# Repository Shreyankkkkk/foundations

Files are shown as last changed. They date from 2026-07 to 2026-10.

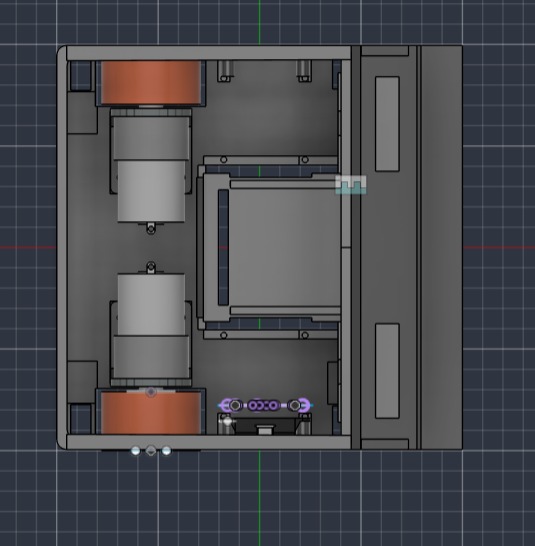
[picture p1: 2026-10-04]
projects/sumo-robot/design/cad-v2/WhatsApp Image 2026-09-25 at 10.48.36.jpeg

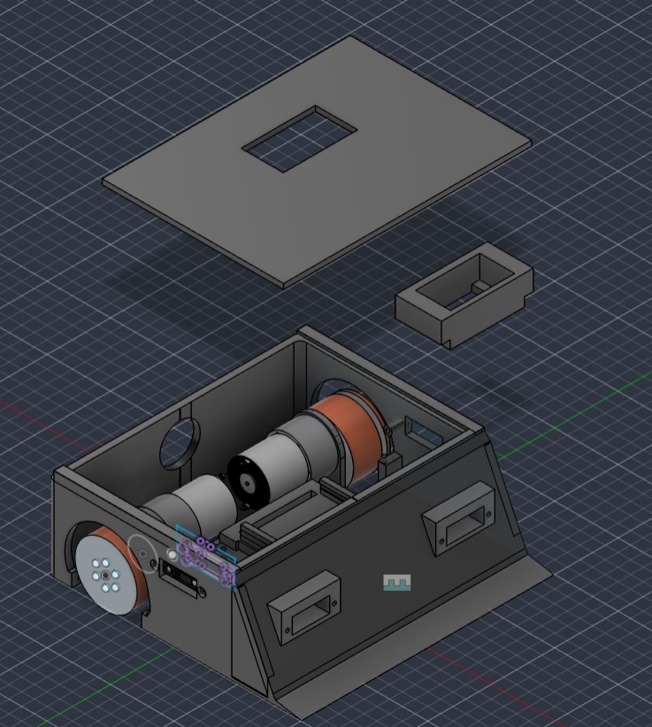
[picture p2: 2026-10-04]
projects/sumo-robot/design/cad-v2/WhatsApp Image 2026-09-25 at 10.48.32.jpeg

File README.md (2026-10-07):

# Foundations

A public log of everything I study, build and earn: notes, exercises, projects, certificates and plans, with dates.

**Shreyank**, second-year Mechatronics Engineering student at the University of Wollongong in Dubai. Long-term goal: quantitative finance, through both discretionary trading and systematic/quant development.
Contact: [LinkedIn](https://www.linkedin.com/in/shreyank-bhatt-63624a382/) · bhattshreyanks@gmail.com

## Where to look

| I want to see | Go to |
|---|---|
| What I did and when | [`journal/`](journal/): one dated ledger per month |
| What I built | [`projects/`](projects/): each project has a `STATE.md` (where it stands) and a `LOG.md` (what changed, when, why) |
| What I studied | [`learning/`](learning/): programming, mathematics, AI, engineering, finance |
| What I earned | [`certificates/`](certificates/): indexed by domain |
| What I plan next | [`roadmap/`](roadmap/) |

## Projects

| Project | Status | Summary |
|---|---|---|
| [`sumo-robot`](projects/sumo-robot/) | Finished (Oct 2026) | Autonomous sumo robot for the Dubai TechBots League SumoX-26; firmware v1.0 to v2.4, sensor calibration, CAD. Retrospective in the folder. |
| [`monte-carlo-simulation`](projects/monte-carlo-simulation/) | Active | Monte Carlo trading simulation in Python (Numba, joblib); modular rewrite in `current/`, earlier versions in `archive/`. |
| [`quant-finance-sim-forage`](projects/quant-finance-sim-forage/) | To redo | Forage quant-finance simulation; early attempt only. |

## Learning

Python (notes + exercises), Git & GitHub, data analysis with pandas (started), embedded C on Arduino (started), statistics (notes), Claude and LLM basics (notes). Details and status: [`learning/README.md`](learning/README.md).

## How this repo is kept

- Structure and rules for AI assistants are in [`AI-CONTEXT.md`](AI-CONTEXT.md). Logging is done with an AI assistant connected to this folder; AI-assisted work is recorded as such in each project's `LOG.md`.
- All names are lowercase kebab-case. Books, vendor files and coursework are kept local and not published.

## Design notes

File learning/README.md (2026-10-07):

# Learning

Notes and exercises, grouped by subject. Layout inside a topic: `notes/`, `exercises/`, `datasets/`, `projects/` (only where there is content). Plans live in `roadmap/`; dates live in `journal/`.

| Area | Folder | Status |
|---|---|---|
| Python | `programming/python` | notes (algorithms, OOP, data structures, debugging) + 17 exercises |
| Git & GitHub | `programming/git-github` | notes + cheat sheet |
| Data analysis | `programming/data-analysis` | started: pandas note + one exercise |
| Embedded C / Arduino | `programming/embedded-arduino` | fundamentals note + exercises 01-04 |
| APIs & automation | `programming/apis-automation` | planned |
| Statistics | `mathematics/statistics-essential` | notes 1-7 + cheat sheet |
| Quant maths plan | `mathematics/quant-math-curriculum.md` | reading plan |
| Claude / LLMs | `ai/notes` | Claude 101, Claude Code, how LLMs work |
| CAD | `engineering/fusion360-cad` | planned |
| Finance | `finance/` | planned |

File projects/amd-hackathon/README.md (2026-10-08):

# AMD Hackathon (Lablab x AMD AI Academy Challenge)

Individual, three-month AMD developer program (2026-09-01 to 2026-12-01): AI Academy courses, bi-weekly mini-challenges (OCR, RAG, agents, fine-tuning), XP leaderboard, cash prizes for the first three builders to reach Legend rank.

- Current status and rules: `STATE.md`
- Dated changes: `LOG.md`
- Digest of the brief: `docs/brief.md`

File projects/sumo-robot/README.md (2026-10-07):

# Sumo-Robot (SumoX-26)

Autonomous sumo robot (Arduino UNO Q, 20x20 cm, 3 kg) built for the Dubai TechBots League SumoX-26. Competed 2026-10-04 and was eliminated after three matches.

Start with `STATE.md` (result, constants with calculations, hardware, rules), then `Retrospective.md` (what worked and what didn't, by stage). `LOG.md` is the history.

| Folder | Holds |
|---|---|
| `docs/specs/` | wiring, strategy and reference documents |
| `docs/rulebook/` | competition rulebook and briefing slides |
| `design/` | `cad-v1` and `cad-v2` models, `parametric` wedge and deck scripts |
| `firmware/strategy/` | firmware versions `v1.0` to `v2.4` (v2.4 was on the board), `CodeGuide.md` |
| `firmware/tests/` | sensor, motor and calibration sketches |
| `notes/` | notes, dated scans (`scans/`), and per-chat summaries (`chat-summaries/`) |

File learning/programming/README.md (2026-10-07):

# Programming

| Folder | Contents |
|---|---|
| `python/` | `notes/` (concept notes with runnable demos), `exercises/` (solved problems), `data-structure-algorithm/` |
| `git-github/` | `notes/` (fundamentals, cheat sheet) |
| `data-analysis/` | `notes/`, `exercises/`, `datasets/` |
| `embedded-arduino/` | `notes/arduino-fundamentals.md`, `exercises/01-04` (blink, button, multi-sensor priority, toggle edge detection) |
| `apis-automation/` | planned |

Index of all learning areas: `../README.md`.

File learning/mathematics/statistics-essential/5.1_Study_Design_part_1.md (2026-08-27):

# Source and attribution

These are my personal study notes based on the Khan Academy Statistics course.

- Course: Statistics
- Provider: Khan Academy
- Source: https://www.khanacademy.org/math/probability
- Copyright: © 2025 Khan Academy. All rights reserved.

## These notes are independently written summaries for educational and reference purposes and are not official Khan Academy course materials.

# Intoduction to Plannning a Study

## Lesson 1 : Identifying a Sample and Population

### Population

A **population** is the **entire group of individuals** that a study is interested in.

$$\boxed{\text{Population}=\text{entire group being studied}}$$

The population is the group that researchers ultimately want to learn about.

---

### Sample

A **sample** is a **subset of the population** that is actually observed, surveyed, or measured.

$$\boxed{\text{Sample}=\text{part of the population actually studied}}$$

The sample is used to gather information about the larger population.

---

### Example: Riverview High School

Administrators at Riverview High School want to know how seniors feel about the lunch offerings in the school's cafeteria.

They randomly survey **100 seniors**.

Therefore:

$$\boxed{\text{Population}=\text{all seniors at Riverview High School}}$$

and:

$$\boxed{\text{Sample}=\text{the 100 seniors who were surveyed}}$$

The 100 seniors are only a subset of all the seniors at the school.

$$
\boxed{\text{Sample}\subseteq\text{Population}}$$

---

### Population vs Sample

| Term | Meaning | Riverview Example |
| --- | --- | --- |
| **Population** | Entire group of interest | All seniors at Riverview High |
| **Sample** | Subset actually studied  | 100 seniors surveyed |

A useful way to remember the difference:

$$
\boxed{\text{Population}=\text{WHO we want information about}}$$

$$
\boxed{\text{Sample}=\text{WHO we actually collect information from}}$$

---

### Why Use a Sample?

Researchers often cannot or do not want to collect data from every member of the population.

Studying the entire population may be:

- impractical
- expensive
- time-consuming
- difficult to organize

Instead, researchers can select a sample and use its results to learn about the population.

The basic process is:

$$
\boxed{\text{Population}\rightarrow\text{Sample}\rightarrow\text{Collect data}\rightarrow\text{Learn about population}}$$

---

### Random Sample

A **random sample** is a sample selected randomly from the population.

In the Riverview example, the administrators randomly select 100 seniors.

$$
\boxed{\text{Random sample}=\text{sample selected randomly from the population}}$$

Random sampling helps reduce the risk that the sample is systematically different from the population.

---

### Identifying the Population

When identifying the population, ask:

> **Who are the researchers trying to learn about?**

For the Riverview example, the researchers want to know how **all seniors at Riverview High** feel about the cafeteria.

Therefore:

$$\boxed{\text{Population}=\text{all seniors at Riverview High}}$$

It is **not**:

- all high school seniors in the world
- all students at Riverview High
- all teenagers

The population must match the group the study is actually trying to understand.

---

### Identifying the Sample

When identifying the sample, ask:

> **Who was actually surveyed, observed, or measured?**

In the Riverview example, the administrators surveyed 100 seniors.

Therefore:

$$\boxed{\text{Sample}=\text{the 100 seniors surveyed}}$$

It is not all seniors at the school because only 100 of them were actually surveyed.

---

### Common Mistakes

#### Mistake 1: Making the population too large

Suppose the study is about seniors at one particular school.

Incorrect:

$$\boxed{\text{Population}=\text{all high school seniors in the world}}$$

Correct:

$$\boxed{\text{Population}=\text{all seniors at the school}}$$

The population depends on the **specific group the researchers want to learn about**.

---

#### Mistake 2: Calling the entire population the sample

If 100 seniors were surveyed, the sample is not all seniors.

Incorrect:

$$\boxed{\text{Sample}=\text{all seniors at Riverview}}$$

Correct:

$$\boxed{\text{Sample}=\text{100 seniors who were surveyed}}$$

---

### Example

A university wants to know how students feel about its online classes.

The university randomly surveys 500 students.

Then:

$$\boxed{\text{Population}=\text{all students at the university}}$$

$$\boxed{\text{Sample}=\text{the 500 students surveyed}}$$

The 500 students provide information that can be used to learn about the larger population.

---

### Quick Exam Strategy

When a question asks you to identify the population and sample:

**Step 1:** Ask who the researchers want to learn about.

$$\boxed{\text{Population}}$$

**Step 2:** Ask who was actually surveyed, observed, or measured.

$$\boxed{\text{Sample}}$$

Remember:

$$\boxed{\text{Population}\rightarrow\text{larger group}}$$

$$\boxed{\text{Sample}\rightarrow\text{smaller group actually studied}}$$

---

### Key Takeaways

> **Population = the entire group we want to learn about.**

$$\boxed{\text{Population}=\text{entire group of interest}}$$

> **Sample = the part of the population that we actually study.**

$$\boxed{\text{Sample}=\text{subset actually studied}}$$

The most important relationship is:

$$
\boxed{
\text{Sample}\subseteq\text{Population}
}
$$

For the Riverview example:

$$\boxed{\text{Population}=\text{all seniors at Riverview High}}$$

$$\boxed{\text{Sample}=\text{100 seniors surveyed}}$$

### Memory Trick

> **Population = WHO you WANT to know about.**
>
> **Sample = WHO you ACTUALLY ask or measure.**

The overall idea:

$$
\boxed{
\text{Sample}
\rightarrow
\text{Use data to learn about}
\rightarrow
\text{Population}
}
$$

---

### Video

[Identifying a sample and population](https://www.youtube.com/watch?v=VPM84_yfx5Q)

---

## Lesson 2 : Generalizing Results to a Population

### What Does It Mean to Generalize?

**Generalizing** means using the results from a sample to make conclusions about a **larger population**.

For example, researchers may survey a sample of students and use their responses to learn about a larger group of students.

The basic idea is:

$$
\boxed{
\text{Sample results}
\rightarrow
\text{Conclusions about a population}
}
$$

However, we can only safely generalize to a population that the sample **properly represents**.

---

### Example: University Residence Halls

A large university has **24 residence halls**.

Estella oversees **12 of those residence halls**.

Her department takes a **large simple random sample** of first-year students who live in those 12 residence halls.

The students are surveyed about their overall satisfaction with campus living.

The important details are:

- The sample contains **first-year students**.
- They live in **Estella's 12 residence halls**.
- The sample was **large**.
- The sample was selected using a **simple random sample**.

Therefore, the survey results can safely be generalized to:

$$
\boxed{
\text{All first-year students who live in those 12 residence halls}
}
$$

---

### Why Can't We Generalize to All First-Year Students?

The sample only includes first-year students who live in the **12 residence halls managed by Estella**.

There may be other first-year students living in the university's other 12 residence halls.

Those students were not part of the population from which the sample was selected.

Therefore:

$$
\boxed{
\text{Cannot generalize to all first-year students at the university}
}
$$

The sample may not represent students living in the other residence halls.

For example, Estella's 12 residence halls could be:

- the closest to campus
- the furthest from campus
- unusually good
- unusually poor
- different in some other way

Because the sample only comes from those 12 halls, we cannot assume that the results apply to students living elsewhere.

---

### Why Does Simple Random Sampling Matter?

A **simple random sample** gives members of the population a fair chance of being selected.

If the sample is a large simple random sample from a particular population, the results can generally be generalized to that population.

The key relationship is:

$$
\boxed{
\text{Random sample}
\rightarrow
\text{Can generalize to the population sampled from}
}
$$

But remember:

> **Random sampling does not automatically allow you to generalize to everyone.**

You can only generalize to the population from which the random sample was actually selected.

---

### The Sampling Population

The **sampling population** is the group from which the sample was actually selected.

In this example:

$$\boxed{\text{Sampling population}=\text{first-year students living in the 12 residence halls}}$$

The sample is randomly selected from this group.

Therefore, this is the population to which the results can be generalized.

---

### Important Distinction

There are three groups to keep track of:

1. **The entire university**
2. **The 12 residence halls managed by Estella**
3. **The students actually surveyed**

The survey only samples from group 2.

Therefore:

$$\boxed{\text{Population}=\text{first-year students living in the 12 residence halls}}$$

and:

$$\boxed{\text{Sample}=\text{large random sample of those students}}$$

---

### What About Students Beyond Their First Year?

The survey only sampled **first-year students**.

Second-year, third-year, and fourth-year students were not included.

Therefore, the results cannot safely be generalized to:

$$
\boxed{
\text{All students living in the 12 residence halls}
}
$$

Why?

Because students beyond their first year may have different experiences and opinions about campus living.

The sample was specifically drawn from **first-year students**.

---

### Generalization Rule

When deciding whether survey results can be generalized, ask:

> **Who could have been selected for the sample?**

The answer identifies the population to which the results can be generalized.

For example:

$$
\boxed{
\text{Sample selected from population}
\rightarrow
\text{Results can be generalized to that population}
}
$$

But:

$$
\boxed{
\text{Sample selected from population A}
\not\rightarrow
\text{Automatically generalizable to population B}
}
$$

---

### Example

Suppose a school has 1,000 students.

Researchers randomly survey 100 students from the entire school.

Then the results can potentially be generalized to:

$$
\boxed{
\text{All 1,000 students at the school}
}
$$

But suppose instead they randomly survey 100 students from only the school's basketball team.

Then the results can only be generalized to the population represented by that sampling process, such as:

$$
\boxed{
\text{Students on the basketball team}
}
$$

You cannot use the basketball team's opinions to automatically represent the entire school.

---

### Large Sample vs Population Coverage

A **large sample** is useful, but size alone does not determine what population you can generalize to.

For example, suppose you survey 5,000 students from only one residence hall.

Even though:

$$
\boxed{\text{Sample size}=5000}
$$

you still cannot automatically generalize the results to students living in every residence hall.

The sample must represent the population you want to make conclusions about.

Therefore:

$$
\boxed{
\text{Large sample}
\neq
\text{automatically representative of everyone}
}
$$

The **sampling method and sampling population** matter.

---

### Key Question for Exams

When asked:

> **"To which population can these results be generalized?"**

Ask:

### Step 1: Who was actually sampled?

Identify the group from which the researchers selected participants.

### Step 2: Was the sample randomly selected?

If it was a random sample, the results can generally be generalized to the population from which that sample was drawn.

### Step 3: Check for restrictions

Look for restrictions such as:

- only first-year students
- only students in certain residence halls
- only members of a particular group
- only people from a particular location

The generalization must respect these restrictions.

---

### Riverview Connection

This connects directly to Lesson 1.

In Lesson 1:

$$\boxed{\text{Population}=\text{all seniors at Riverview High}}$$

$$\boxed{\text{Sample}=\text{100 seniors surveyed}}$$

Because the 100 seniors were randomly sampled from the seniors at the school, the survey results can potentially be generalized to:

$$
\boxed{
\text{all seniors at Riverview High}
}
$$

The same principle applies here.

---

### Important Exam Rule

$$
\boxed{
\text{Random sample}
\rightarrow
\text{generalize to the population sampled from}
}
$$

But:

$$
\boxed{
\text{Do not generalize beyond the population represented by the sample}
}
$$

For the university example:

$$
\boxed{
\text{Generalize to:}
\text{first-year students in the 12 residence halls}
}
$$

Not:

$$
\boxed{
\text{All students at the university}
}
$$

and not:

$$
\boxed{
\text{All first-year students at the university}
}
$$

---

### Key Takeaways

> **A survey's results can only be generalized to the population from which the sample was appropriately selected.**

$$
\boxed{
\text{Sample}
\rightarrow
\text{Sampling population}
\rightarrow
\text{Generalization}
}
$$

A **large simple random sample** allows us to make conclusions about the population from which the sample was drawn.

$$
\boxed{
\text{Large simple random sample}
\rightarrow
\text{Generalizable to its sampling population}
}
$$

But remember:

$$
\boxed{
\text{Random sampling does not mean you can generalize to everyone}
}
$$

You must respect the characteristics of the sampled population.

### Memory Trick

> **Ask: "Who could have been picked?"**

That group is the population you can generalize to.

For the university example:

$$\boxed{\text{Who could have been picked?}=\text{first-year students living in the 12 residence halls}}$$

Therefore:

$$
\boxed{
\text{Generalize to that group}
}
$$

---

### Video

[Generalizing survey results to a population](https://www.youtube.com/watch?v=2FXwGI_debU)

---

## Lesson 3 : Types of Statistical Studies

### Experiment vs Observational Study

The two main types of statistical studies are:

### Experiment

An **experiment** actively assigns subjects to different groups and applies a treatment or condition.

Typically:

- Subjects are assigned to a **treatment group** or **control group**.
- The treatment group receives the treatment.
- The control group may receive a placebo or no treatment.
- The results are compared between the groups.

$$
\boxed{\text{Experiment}\rightarrow\text{actively assign treatments and observe results}}
$$

### Observational Study

An **observational study** does **not** assign treatments or actively put subjects into groups.

Instead, researchers collect and analyze data about what already exists.

$$
\boxed{\text{Observational study}\rightarrow\text{observe and collect data without assigning treatment}}
$$

---

### Types of Observational Studies

There are three important types:

| Type | What it does | Time direction |
| --- | --- | --- |
| **Retrospective** | Uses past data | Looks backward |
| **Prospective** | Collects data going forward | Looks forward  |
| **Sample survey** | Collects information from a sample now | Present |

---

#### Retrospective Study

A **retrospective study** looks at data from the **past**.

Researchers use existing records or previously collected information.

Memory trick:

> **Retro = backward**

$$
\boxed{\text{Retrospective}\rightarrow\text{past data}}
$$

**Example:** Analyzing students' Khan Academy usage from previous years.

---

#### Prospective Study

A **prospective study** follows a sample **into the future** and collects data over time.

Researchers select the sample first, then track the subjects.

Memory trick:

> **Prospective = forward**

$$
\boxed{\text{Prospective}\rightarrow\text{future data}}
$$

**Example:** Select 100 people and track their daily habits for the next year.

---

#### Sample Survey

A **sample survey** collects information from a sample **at the present time**, usually by asking questions or recording current information.

$$
\boxed{\text{Sample survey}\rightarrow\text{collect information now}}
$$

**Example:** Randomly selecting students and asking them how satisfied they currently are with their school.

---

### Quick Decision Guide

Ask these questions:

**1. Are researchers actively assigning a treatment?**

$$
\boxed{\text{Yes}\rightarrow\text{Experiment}}
$$

**2. No treatment is assigned. Are they using past data?**

$$
\boxed{\text{Yes}\rightarrow\text{Retrospective}}
$$

**3. No treatment is assigned. Are they tracking a sample into the future?**

$$
\boxed{\text{Yes}\rightarrow\text{Prospective}}
$$

**4. No treatment is assigned. Are they collecting information from people now?**

$$
\boxed{\text{Yes}\rightarrow\text{Sample survey}}
$$

---

#### Key Takeaway

$$\boxed{\text{Experiment}=\text{assign treatment}}$$

$$\boxed{\text{Retrospective}=\text{look backward}}$$

$$\boxed{\text{Prospective}=\text{look forward}}$$

$$\boxed{\text{Sample survey}=\text{ask/observe now}}$$

#### Memory Trick

> **Experiment = DO something**  
> **Retrospective = PAST**  
> **Prospective = FUTURE**  
> **Sample survey = NOW**

### Video

[Types of Studies](https://www.youtube.com/watch?v=zmXBbHDUgY4)

---

## Lesson 4 : Identifying Observational Studies

### Observational Study

An **observational study** collects data by observing existing conditions without assigning treatments.

The goal is often to identify a **relationship or correlation between variables**.

$$\boxed{\text{Observational study}=\text{observe variables without assigning treatment}}$$

---

### Example: Naming Cows

Researchers surveyed farmers in Great Britain about:

- whether their cows were given names
- the cows' milk yield

They found that farms where cows were named had an average milk yield **258 liters higher** than farms where cows were not named.

This is an **observational study** because the researchers did not tell farmers whether to name their cows. They simply observed what was already happening.

---

### Why It Is Not an Experiment

In an experiment, researchers would actively assign farmers to groups.

For example:

- Group 1 → name their cows
- Group 2 → do not name their cows

Then researchers would compare milk yields.

That did **not** happen in this study.

$$
\boxed{
\text{No treatment assignment}
\rightarrow
\text{Not an experiment}
}
$$

---

### Correlation vs Causation

The study found a **positive correlation** between naming cows and milk yield.

$$
\boxed{
\text{Naming cows}
\leftrightarrow
\text{Higher milk yield}
}
$$

However, this does **not** prove that naming cows causes higher milk production.

The correct conclusion is only that the variables are **associated/correlated** in the observed population.

$$
\boxed{
\text{Correlation}
\neq
\text{Causation}
}
$$

---

### Confounding Variable

A **confounding variable** is another variable that may be related to both variables being studied and could explain their association.

For example, a farmer's treatment of cows could affect both:

- whether cows are named
- milk production

Therefore, the observed relationship between naming cows and milk yield might be partly or entirely explained by another variable.

$$
\boxed{
\text{Confounding variable}
\rightarrow
\text{may influence both variables}
}
$$

---

### What Can Be Concluded?

Because this is an observational study, researchers can conclude that:

$$
\boxed{
\text{There is a positive correlation between naming cows and milk yield among the farmers studied}
}
$$

They **cannot** conclude:

$$
\boxed{
\text{Naming cows causes higher milk yield}
}
$$

---

### Quick Decision Guide

When identifying a study, ask:

**1. Did researchers actively assign a treatment?**

$$
\boxed{\text{Yes}\rightarrow\text{Experiment}}
$$

**2. Did they simply observe existing conditions and look for relationships?**

$$
\boxed{\text{Yes}\rightarrow\text{Observational study}}
$$

Then ask:

> **Can the study prove causation?**

For an observational study:

$$
\boxed{
\text{Usually no causal conclusion}
}
$$

Instead:

$$
\boxed{
\text{Observational study}
\rightarrow
\text{association/correlation}
}
$$

---

### Key Takeaways

> **Observational study = observe without assigning treatment.**

$$
\boxed{
\text{Observational}
\rightarrow
\text{correlation/association}
}
$$

> **Correlation does not prove causation.**

$$
\boxed{
\text{Correlation}
\neq
\text{Causation}
}
$$

> **Confounding variables can help explain an observed association.**

### Memory Trick

> **Experiment = DO something.**  
> **Observational = WATCH what happens.**  
> **Correlation = relationship, not proof of cause.**

---

### Video

[Identifying observational studies](https://www.youtube.com/watch?v=tHFyaoIrV14)

---

## Lesson 5 : Understanding Causality

### Association vs Causality

An **association** means two variables are related.

**Causality** means a change in one variable actually **causes** a change in another.

$$
\boxed{
\text{Association}
\neq
\text{Causation}
}
$$

An observational study can show an association, but by itself it generally cannot prove that one variable causes another.

---

### Example: Smartphone Usage and Happiness

A study used approximately **5,000 randomly selected teenagers** and found that teenagers who spent more time on smartphones were, on average, less happy.

This shows an **association** between:

- smartphone usage
- happiness

$$
\boxed{
\text{More smartphone use}
\leftrightarrow
\text{Lower happiness}
}
$$

However, it does **not** prove:

$$
\boxed{
\text{More smartphone use}
\rightarrow
\text{Lower happiness}
}
$$

Jerry's conclusion that smartphone usage **causes** teenagers to be less happy is therefore not valid.

---

### Why Can't We Prove Causation?

There are several possible explanations for the association.

#### 1. Reverse Causation

The direction of causality could be reversed.

For example:

$$
\boxed{
\text{Lower happiness}
\rightarrow
\text{More smartphone use}
}
$$

Less happy teenagers might use their smartphones more.

---

#### 2. Confounding Variable

A third variable could affect both variables.

$$
\boxed{
\text{Confounding variable}
\rightarrow
\begin{cases}
\text{smartphone usage}\\
\text{happiness}
\end{cases}
}
$$

For example, another factor could make a teenager both less happy and more likely to use a smartphone.

---

### When Can We Make a Causal Conclusion?

A well-designed **experiment** can provide evidence for causality.

Researchers can:

1. Randomly assign subjects to groups.
2. Give the treatment group a treatment.
3. Give the control group no treatment or a placebo.
4. Compare the outcomes.

For example:

$$
\boxed{
\text{Random assignment}
\rightarrow
\text{Treatment vs Control}
\rightarrow
\text{Compare outcomes}
}
$$

Because the researchers actively assign the treatment, an experiment can establish evidence of a **cause-and-effect relationship**.

---

### Observational Study vs Experiment

| Study type | What researchers do | Causal conclusion? |
|---|---|---|
| **Observational study** | Observe existing conditions | Generally **no** |
| **Experiment** | Assign treatments to groups | **Can** support causality |

The key difference is:

$$\boxed{\text{Experiment}=\text{researchers assign treatment}}$$

$$\boxed{\text{Observational study}=\text{researchers observe without assigning treatment}}$$

---

### Important Exam Rule

If a question describes a study where researchers **only observe** people's existing behavior:

$$
\boxed{
\text{Association/correlation}
\text{ can be concluded}
}
$$

but:

$$
\boxed{
\text{Causation}
\text{ cannot generally be concluded}
}
$$

If researchers **randomly assign a treatment**:

$$
\boxed{
\text{Experiment}
\rightarrow
\text{causal conclusions may be possible}
}
$$

---

### Key Takeaways

> **Observational study → association, not causation.**

> **Experiment with appropriate random assignment → can provide evidence of causation.**

$$
\boxed{
\text{Observe}
\rightarrow
\text{Association}
}
$$

$$
\boxed{
\text{Randomly assign treatment}
\rightarrow
\text{Causality can be investigated}
}
$$

### Memory Trick

> **Observe = Association**  
> **Assign = Causation**

---

### Video

[Understanding when a conclusion about causality can be made from a study](https://www.youtube.com/watch?v=xSvvjdZjgl8)

---

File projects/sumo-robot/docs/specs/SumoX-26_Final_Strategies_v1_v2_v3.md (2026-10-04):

# SumoX-26 Final Strategy & Behavior Specification

This document serves as the definitive guide to the behavior and logic implemented in the SumoX-26 robot. It describes the shared core, the specific combat strategies, and the tactical optimizations that govern the robot's actions.

## 1. System Architecture & Priority
The robot operates as a high-priority state machine. In every loop, the following priority is enforced:
1. **Emergency Stop**: If the `START_BUTTON` (A4) is released, motors stop immediately and the robot returns to a waiting state.
2. **Edge Recovery**: If any edge sensor detects white, all other logic is bypassed to execute `edgeRecover()`. This event also resets target tracking state to prevent "ghost" attacks after recovery.
3. **Target Tracking**: If an opponent is detected, the robot enters the `approachTarget()` and `attack()` sequence.
4. **Search Arc**: If no opponent is detected and the robot is not in a blind-window attack, it executes a circular search sweep.

---

## 2. The Shared Core (Common Logic)

### A. Startup & The Randomized Start
To avoid predictability and "wedge-locks" at the start of a match, the robot uses a **Randomized Start Palette**.
- **The Sequence**: After the mandatory 5-second countdown, the robot randomly selects one of four maneuvers:
    - **Balanced Offset**: 200ms pivot $\rightarrow$ 300ms forward.
    - **The Aggressor**: 100ms pivot $\rightarrow$ 400ms forward (fastest approach).
    - **The Flanker**: 300ms pivot $\rightarrow$ 200ms forward (wide angle).
    - **The Blitz**: 0ms pivot $\rightarrow$ 300ms straight burst (maximum aggression).
- **Randomness**: The system is re-seeded using `micros()` at the moment the round-start button is confirmed, ensuring unique patterns even across power-cycles.
- **Safety**: All start maneuvers are safety-aware; if an edge is hit during the start move, it immediately triggers `edgeRecover()`.

### B. Sensor Processing
- **Opponent Sensing**: GP2Y0A21 sensors are sampled every 40ms. A rolling median buffer of 5 samples is used to eliminate noise before comparing against `DIST_THRESHOLD` (400).
- **Sample Gating**: Tracking logic is gated by the sample count; state changes (like counting lost targets) only occur when a new physical sample is read, preventing CPU-speed logic errors.
- **Edge Sensing**: TCRT5000 sensors are polled digitally. Any "White" detection (`HIGH`) triggers an immediate interrupt.

### C. Edge Recovery & Repositioning
- **`edgeRecover()`**: A state machine that determines the direction of the edge hit (front, back, or corner) and executes a deterministic retreat and pivot. It includes ambiguity handling (e.g., safe-pivot fallbacks) when multiple sensors trigger.
- **`reposition()`**: A fallback maneuver used when a target is lost. It nudges the robot forward or backward for 300ms to change its vantage point.
- **`executeBalancedOffset()`**: A specific version of repositioning used after losing a target, shifting the robot slightly to avoid a head-on collision on the next attempt.

---

## 3. Combat Strategies

### Strategy 1: Flanking (Proportional Tracking)
Designed for smooth, curving approaches.
- **Approach**: Uses a P-controller based on the difference between left and right sensor readings.
- **Hard Override**: If a side sensor is triggered, the robot bypasses proportional math and executes a maximum-rate turn to snap back onto the target.
- **Steering**: Otherwise, it calculates a `correction` value ($\text{Kp} = 0.5$). The robot doesn't pivot; it drives in a continuous arc toward the opponent.
- **Engagement**: Once the opponent is squared up (error $< 20$), it commits to the attack.

### Strategy 2: Baseline (Discrete Tracking)
Designed for reliability and sharp corrections.
- **Approach**: Uses discrete steering states (`STEER_LEFT`, `STEER_RIGHT`, `STEER_STRAIGHT`).
- **Hysteresis**: To prevent "jitter" between left and right turns, the robot uses a `SIDE_TURN_MARGIN` (25) and a `SIDE_TURN_HYSTERESIS` (10) zone.
- **Confirmation**: A steering change is only committed if the target remains in that direction for 50ms.
- **Engagement**: Once front sensors are strongest, it commits to the attack.

---

## 4. Tactical Optimizations (The "Combat Edge")

### A. Active Push Correction
The robot does not simply drive straight when attacking. It applies a continuous steering correction during the push:
- **Logic**: `drive(ATTACK_SPEED + correction, ATTACK_SPEED - correction)`.
- **Purpose**: Keeps the robot's wedge centered on the opponent even if the opponent drifts or the robot slips.
- **Gain (Strategy 2)**: $\text{Push Kp} = 2$.

### B. The Hammer Attack & Blindness Protection
To win a "lock" where both robots are pushing against each other, the robot employs PWM oscillation:
- **Hammer Logic**: Rapidly toggles the base attack speed between `ATTACK_SPEED` (240) and `(ATTACK_SPEED - HAMMER_AMPLITUDE)` (190) every 100ms to break static friction.
- **Blindness Protection**: Once a push is committed (latched via `attackDeadline`), the robot continues to hammer for a short window (`ATTACK_COMMIT_MS`) even if sensor contact is lost. This ensures the robot doesn't abort an attack just because the opponent entered the sensor's near-field blind zone.

---

## 5. Calibration Cheat Sheet (Current Values)

| Parameter | Value | Unit/Description |
|---|---|---|
| **Sensing** | | |
| `DIST_THRESHOLD` | 400 | ADC value for detection |
| `SENSOR_SAMPLES` | 5 | Rolling buffer size |
| **Search** | | |
| `SEARCH_SLOW_SPEED` | 120 | PWM for slow motor |
| `SEARCH_FAST_SPEED` | 180 | PWM for fast motor |
| `SEARCH_FIRST_ARC_MS` | 600 | Initial pivot duration |
| `SEARCH_ARC_FLIP_MS` | 1100 | Standard arc flip duration |
| **Approach** | | |
| `APPROACH_SPEED` | 165 | Base approach speed |
| `TURN_SPEED` | 100 | Pivot speed during approach |
| `S1_Kp` | 0.5 | Proportional gain |
| `S1_DEADBAND` | 20 | Error threshold for attack |
| `S2_MARGIN` | 25 | Side detection threshold |
| **Attack** | | |
| `ATTACK_SPEED` | 240 | Base push power |
| `HAMMER_AMPLITUDE` | 50 | PWM oscillation depth |
| `HAMMER_PERIOD_MS` | 100 | Oscillation frequency |
| `S2_PUSH_KP` | 2 | Push correction gain |
| **Safety** | | |
| `REPOSITION_MS` | 300 | Nudge duration |
| `EDGE_RECOVER_SPEED` | 170 | Retreat speed |
| `OFFSET_SPEED` | 150 | Maneuver speed |

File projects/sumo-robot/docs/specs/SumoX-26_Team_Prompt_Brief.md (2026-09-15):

# SumoX-26 Team Brief — paste this into your own Claude chat

We're building an autonomous sumo robot for the **Dubai Techbots League SumoX-26** (Besomi Academy × Arduino × Qualcomm × Canadian University Dubai). Use the block below to get Claude up to speed instantly, then jump to your role's starter prompt.

---

## STEP 1 — Paste this shared context into a new Claude chat first

```
I'm on a team building an autonomous sumo robot for the Dubai Techbots League
SumoX-26 competition (organized by Besomi Academy, with Arduino and Qualcomm
as sponsors). Here are the key rules:

- Weight limit: 3 kg max
- Footprint: 20cm x 20cm max at start (no height limit, and the robot CAN
  change shape/size after movement begins, as long as all parts stay attached
  to the main body)
- Controller: MUST use the Arduino UNO Q as the primary/only microcontroller
  (no other microcontrollers allowed). It's a dual-brain board: an STM32
  microcontroller for real-time motor/sensor control, plus a Qualcomm
  QRB2210 Linux processor capable of running a camera and AI models.
- The robot must be 100% autonomous - remote control is strictly banned
- Arena: circular wood, 1.5m diameter, white 3cm frame, black surface, two
  brown 20cm center lines
- Round: max 3 minutes, robot must stay stationary for 5 seconds after
  activation before moving
- Match = best of 2 rounds (3rd if tied 1-1)
- Rule violations to avoid: front of the robot (blade/wedge) must NOT be
  white or any color that could interfere with sensor readings; no magnets,
  suction, vacuum wheels, or adhesives to grip the arena; no liquids, gases,
  powders, or projectiles; 3 warnings in one round = automatic round loss;
  6 total warnings = disqualification; any robot part detaching = 1 warning
  per part

My team already has a full build playbook covering: sumo robot world
championship research (All Japan Robot-Sumo Tournament history and past
winners), mechanical design (low center of gravity, wedge front, motor/gear
selection), electronics (motor driver, battery, opponent + edge sensors),
and a search -> attack -> edge-avoid programming logic. I'm now going deeper
on one specific part of the build. Please treat me as a beginner in this
specific area and build up my understanding step by step as we go, the same
way you'd teach someone new to the topic, then increase depth based on my
follow-up questions.
```

---

## STEP 2 — Add your role's starter prompt on top of that

Pick whichever matches what you're focusing on. If your team hasn't split roles yet, use the General one.

### 🔧 Mechanical / chassis lead
```
My focus is the mechanical build: chassis, wedge front, wheels, motor
mounting, and weight distribution. Help me design this step by step -
starting with material choice (aluminum vs polycarbonate vs HDPE), then
chassis shape and wedge geometry, then wheel/motor mounting, then a full
weight budget that lands at or just under 3kg with room for ballast.
Ask me what tools/materials I actually have access to before recommending
specifics.
```

### ⚡ Electronics / sensors lead
```
My focus is the electronics: the Arduino UNO Q setup, motor driver
selection, battery choice, and the opponent-detection + edge-detection
sensors. Walk me through setting up the UNO Q from scratch first (App Lab,
the MCU vs MPU split, running a first test sketch), then help me pick and
wire a motor driver and sensors that fit a 3kg autonomous sumo robot. Explain
each component's job before we pick parts.
```

### 💻 Programming / code lead
```
My focus is the code: the robot's decision logic (search -> attack ->
edge-avoid state machine) running on the Arduino UNO Q. Help me build this
from scratch, starting with the simplest possible version (basic edge
avoidance + move forward), then layer in opponent detection, then attack
behavior, then tuning. If it's useful, also explain how I could eventually
use the UNO Q's camera/AI side for smarter opponent detection as a stretch
goal - but let's get the reliable IR-sensor version working first.
```

### 🧭 General / not yet specialized
```
I don't have a specific role locked in yet. Can you help me understand the
full build process end to end at a beginner level - mechanical, electronics,
and code - so I can see which part I'm most drawn to, then we go deep on
that one?
```

---

## Notes for whoever's coordinating

- Everyone should also upload the actual **Dubai Techbots League SumoX-26 Rulebook PDF** to their own chat if they have it, so their Claude has the full original wording, not just this summary.
- Since each teammate's chat is separate, decisions made in one chat won't automatically show up in another — plan for someone (probably the Team Leader) to consolidate what each person's chat produces into one shared doc or group chat before final assembly.
- If two teammates' chats land on conflicting recommendations (e.g. different motor torque suggestions), that's normal — bring both back to the group and decide together rather than assuming either Claude session has the full picture.

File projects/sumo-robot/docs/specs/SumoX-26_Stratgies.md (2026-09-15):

# Sumo Robot Strategy Specs — SumoX-26 (3kg class)

Hardware reference (from wiring diagram):
- LEFT BTS7960: RPWM → D5, LPWM → D6, R_EN+L_EN → D7
- RIGHT BTS7960: RPWM → D9, LPWM → D10, R_EN+L_EN → D8
- GP2Y0A21 distance sensors ×4 (analog, opponent detection): A0, A1, A2, A3
  - Assign each to a mounting position before coding, e.g. FL (front-left), FC-L (front-center-left), FC-R (front-center-right), FR (front-right)
- TCRT5000 edge sensors ×4 (digital, HIGH on black / LOW on white or vice versa — confirm with a multimeter test first): D3, D4, D12, D13
  - Assign each to a corner: e.g. front-left, front-right, back-left, back-right
- Start button: D2 + GND

Tunables to determine through bench testing (placeholders — do not guess final values, calibrate against your actual sensors and arena):
- `DIST_THRESHOLD` — raw ADC value at which a GP2Y0A21 reading counts as "opponent detected"
- `EDGE_THRESHOLD` — digital state that counts as "white detected" per TCRT5000
- `PREDICT_WINDOW_MS` — how long to keep turning after signal loss (Strategy 2 only)
- `SWEEP_ANGLE_MS` — motor-on time for one side of the fallback oscillation (Strategy 2 only)
- `SPIN_STEP_MS` — motor-on time per search increment (Strategy 3 only)

---

## SHARED CORE (build this first, all 3 strategies call into it)

1. **Setup**: initialize all pins (motor PWM/enable pins as OUTPUT, GP2Y0A21 pins as ANALOG INPUT, TCRT5000 pins as INPUT, start button as INPUT_PULLUP). Do not enable motors yet.
2. **Wait for start signal**: poll the start button (or however the round is triggered). On trigger, begin the mandatory 5-second stationary window — sensors already reading, motors still at zero output.
3. **`readDistanceSensors()`**: read all 4 GP2Y0A21 analog pins each loop, return an array/struct of 4 values. Push each into a small rolling history buffer (last 3–5 samples per sensor) for use by Strategy 2.
4. **`checkEdges()`**: read all 4 TCRT5000 digital pins each loop. Return true immediately if any reads "white." This function must be called and checked *before* any drive command is issued, every loop, in every strategy — no exceptions.
5. **`edgeRecover(side)`**: reverse both motors briefly, then pivot away from the triggering side, then return control to the active strategy's search state.
6. **`attack()`**: drive both motors forward at full matched PWM. Call only once the target sensor is roughly front-facing. No steering corrections once called — commit fully.
7. **Main loop structure** (applies to all 3 strategies):
   ```
   loop():
     if checkEdges(): edgeRecover(triggeringSide); return
     readDistanceSensors()
     run the active strategy's state machine using the fresh sensor data
   ```

---

## STRATEGY 1 — Sit, Wait, Scan, Move-Toward-Angle, Attack

No prediction, no rotation search. Stay stationary until a detection occurs, square up, then commit.

1. **IDLE**: motors at zero, keep calling `readDistanceSensors()` and `checkEdges()` every loop.
2. **DETECT**: if any sensor's latest reading crosses `DIST_THRESHOLD`, move to TURN state. If multiple sensors cross it, pick the one with the strongest (closest) reading.
3. **TURN**: apply differential PWM (motor on the opposite side of the detected sensor runs, motor on the same side slows/stops) to rotate toward the detected sensor's direction. Keep reading sensors each loop.
4. **CHECK-SQUARED**: once the front-center sensor(s) become the strongest reading (i.e., you're roughly facing the target), exit TURN and call `attack()`.
5. **ATTACK**: call `attack()`. Stay in this state until either (a) `checkEdges()` fires (handled by shared core, interrupts everything), or (b) all sensors drop below threshold for several consecutive loops (target lost) — then return to IDLE.
6. **LOOP**: after an edge recovery or a lost target, return to IDLE and repeat from step 1.

---

## STRATEGY 2 — Sit, Wait, Scan, Predict, Turn, Attack

Same as Strategy 1, plus a predictive-continuation layer when the signal disappears mid-engagement, and a bounded fallback sweep instead of giving up.

1. **IDLE**: same as Strategy 1 step 1.
2. **DETECT**: same as Strategy 1 step 2. Also record the detected sensor's direction and the loop's timestamp as `lastKnownDirection` and `lastSeenTime`.
3. **TURN**: same as Strategy 1 step 3, continuously updating `lastKnownDirection` while a signal is present.
4. **CHECK-SQUARED → ATTACK**: same as Strategy 1 steps 4–5, also continuously updating `lastKnownDirection` while attacking (in case the opponent slides off to one side mid-charge).
5. **SIGNAL-LOST**: if all sensors drop below threshold while in TURN or ATTACK, do NOT return to IDLE immediately. Instead:
   - Enter PREDICT state: keep turning in `lastKnownDirection` for up to `PREDICT_WINDOW_MS`, re-checking sensors every loop in case the target reappears (if it does, jump straight back to TURN/ATTACK as appropriate).
6. **FALLBACK SWEEP**: if `PREDICT_WINDOW_MS` elapses with nothing detected, perform a bounded oscillation: turn one direction for `SWEEP_ANGLE_MS`, then the other direction for `SWEEP_ANGLE_MS`, checking sensors continuously. If detected during the sweep, jump to TURN.
7. **GIVE UP TO IDLE**: if the sweep also finds nothing after a set number of oscillations, return to IDLE and repeat from step 1.

---

## STRATEGY 3 — Rotate, Scan, Attack

Simplest and most robust. No stationary phase beyond the mandatory 5s, no prediction — continuous rotation until something is found.

1. **SEARCH**: starting the moment the 5s window ends, rotate continuously in one direction (one motor forward, one motor reverse, or one motor forward/one motor stopped — pick whichever turn radius suits your wedge geometry) at a moderate speed. Read all 4 sensors every loop.
2. **DETECT**: the instant any sensor crosses `DIST_THRESHOLD`, stop rotating.
3. **SQUARE-UP** *(optional, can be skipped for max simplicity)*: brief correction turn toward the strongest sensor before attacking, same logic as Strategy 1 step 3–4. If skipped, just attack immediately in whatever heading you stopped at.
4. **ATTACK**: call `attack()`. Stay until edge-override fires or the target is lost for several consecutive loops.
5. **LOOP**: on lost target or after edge recovery, return to SEARCH (step 1) and resume rotating.

---

## Suggested build/test order

1. Shared core (sensor reads, edge-override, attack) — test in isolation first.
2. Strategy 3 — fewest states, fastest to get working end-to-end. This is your safety-net baseline.
3. Strategy 1 — small delta from Strategy 3 (swap rotate-search for stay-still-and-turn-to-signal).
4. Strategy 2 — build last, since `PREDICT_WINDOW_MS` and `SWEEP_ANGLE_MS` need real bench tuning against your actual sensors and motor response time.

Wire a mode switch (digital input pin, or a `#define STRATEGY 1/2/3` flipped before each flash) so all three can be tested head-to-head in practice matches before deciding which one goes into the actual competition.

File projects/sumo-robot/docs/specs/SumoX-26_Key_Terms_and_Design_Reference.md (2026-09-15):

# SumoX-26 Build — Key Terms & Design Reference

A working glossary of everything you need to understand to design this robot correctly, tied to your actual components (JSumo Titan 12V/200RPM motors, 52×30mm wheels, Arduino Uno Q) and the Dubai Techbots League rulebook.

---

## 1. Motor & Drivetrain Terms

| Term | What it means | Why it matters for your build |
|---|---|---|
| **Stall torque** | The maximum rotational force a motor produces when its shaft is prevented from turning at all (0 RPM), usually given in kg·cm or N·m. | Your Titan motor's 10.35 kg·cm stall torque is the number that determines your maximum theoretical push force — this is what you're fighting the opponent with during contact. |
| **Stall current** | The current a motor draws when stalled — always much higher than running current, since there's no back-EMF to limit it. | Your motor draws 4.1A at stall. This is the number your motor driver and power system (fuses, wiring gauge, capacitors) must be rated to survive repeatedly, since ramming an opponent puts the motor near stall constantly. |
| **No-load current / no-load speed** | Current drawn and RPM reached when the motor spins freely with nothing attached. | Your motor's 60mA no-load current tells you baseline power draw when just driving around, not pushing. |
| **RPM (output)** | Rotational speed of the *output shaft*, after any internal gearbox — not the raw motor speed. | Your "200 RPM" spec is already the geared-down output speed, which is what determines your wheel speed. |
| **Gear ratio** | The reduction between the motor's internal shaft speed and the output shaft speed (e.g., 60:1 means the motor spins 60 times for every 1 output rotation). | Higher ratios trade speed for torque. Your Titan's built-in 60:1 gearbox is fixed — you're not choosing this yourself, but you should understand *why* it's high (sumo needs torque over speed). |
| **kg·cm (kilogram-centimeter)** | A torque unit — the force (in kgf) applied at a 1cm lever arm. Convert to linear push force at the wheel by dividing by wheel radius (in cm). | This is how you calculated push force per wheel earlier: 10.35 kg·cm ÷ 2.6cm radius (52mm wheel) ≈ 3.98 kgf per wheel. |
| **Watts (motor power rating)** | Electrical power the motor is designed to handle continuously (V × A). | Used to size your power system and confirm the motor won't overheat under sustained load. |

---

## 2. Traction & Mechanical Terms

| Term | What it means | Why it matters for your build |
|---|---|---|
| **Coefficient of friction (μ)** | A ratio describing how much grip exists between two surfaces (wheel and arena floor). Max friction force = μ × Normal force (weight on the wheel). | This is your *actual* limiting factor, not motor torque — if μ × weight is less than your motor's theoretical push force, your wheels slip instead of pushing. |
| **Contact patch** | The area of wheel actually touching the ground. | Wider wheels (your 52×30mm) have a larger contact patch, which increases usable grip before slipping — this is why we picked it over the narrower 43×11mm option. |
| **Wedge angle** | The angle of your robot's front plate relative to the ground. | 8–12° (your target) lets the wedge slide under an opponent's chassis to lift/destabilize them, while staying shallow enough not to dig into the arena floor. |
| **Ground clearance** | Gap between the wedge's leading edge and the arena floor. | Your 0.5–1mm target is tight enough to get under most opponents without scraping or catching on the floor surface. |
| **Center of gravity (CG)** | The point where a robot's weight is balanced. | A low, rear-biased CG improves push stability and resistance to being lifted or flipped by an opponent's wedge. |
| **Weight distribution** | How the robot's total mass is spread across its footprint, especially over the drive wheels. | More weight on the drive wheels increases normal force → increases available friction → increases usable push force (ties directly into the μ × N relationship above). |

---

## 3. Electrical & Power System Terms

| Term | What it means | Why it matters for your build |
|---|---|---|
| **H-bridge** | A switching circuit (the core of any motor driver) that lets a motor spin forward or backward by controlling current direction. | Every motor driver you're evaluating (BTS7960, Cytron, etc.) is built around this. |
| **Motor driver current rating (continuous vs. peak)** | Continuous = current a driver can sustain indefinitely without overheating; peak = brief current it can survive. | Your driver needs continuous rating comfortably above your motor's 4.1A stall current — this was the deciding factor when comparing driver options earlier. |
| **PWM (Pulse Width Modulation)** | A technique for controlling motor speed by rapidly switching power on/off, varying the % of time it's "on" (duty cycle). | This is how your Arduino Uno Q will vary drive speed for PID-based steering corrections rather than just full on/off. |
| **Brownout** | A voltage drop severe enough to reset or glitch a microcontroller, often caused by a sudden current spike elsewhere in the circuit. | Your spec flagged this directly — motor stall current spikes on impact can brown out the Uno Q mid-match if the power system isn't buffered. |
| **Bulk/decoupling capacitors** | Capacitors placed near a power input to absorb sudden current demand spikes, keeping voltage stable. | The fix for the brownout risk above — placed on your VIN line. |
| **Voltage regulator / BEC (Battery Eliminator Circuit)** | A circuit that converts battery voltage down to a stable voltage for your control electronics, separate from the main motor power line. | Keeps your Uno Q's logic supply clean and isolated from the noisy, current-hungry motor circuit. |

---

## 4. Control & Sensing Terms

| Term | What it means | Why it matters for your build |
|---|---|---|
| **PID controller** (Proportional-Integral-Derivative) | An algorithm that continuously calculates the error between a target and current value, then smoothly adjusts output — instead of a jerky on/off response. | Central to your strategy: used both for smooth opponent-tracking turns and for keeping two drive motors matched during a straight-line charge. |
| **Kp, Ki, Kd** | The three tuning constants of a PID loop — Proportional (reacts to current error), Integral (corrects accumulated past error), Derivative (dampens overshoot by reacting to rate of change). | These *cannot* be copied from another robot — you'll tune them empirically on your assembled robot, as your spec correctly noted. |
| **Debounce / debounce timing** | Filtering logic that ignores rapid, spurious sensor state changes and only reacts to a sustained signal. | Prevents your robot from twitching left-right when both opponent sensors briefly trigger at once near contact. |
| **ADC (Analog-to-Digital Conversion)** | The process of converting a sensor's continuous analog voltage (like an IR distance sensor's output) into a digital value the Uno Q can read. | Relevant because the Uno Q's architecture differs from a classic AVR Arduino — worth confirming its analog input specs directly, since it's a newer Linux-based board. |
| **IR reflectance (edge) sensor** | A sensor that shines infrared light down and measures reflection to distinguish the dark arena floor from "no floor" (i.e., the edge). | Your edge-detection system — must be tuned against the rulebook's white 3cm arena frame, since the sensor is reading contrast, not distance. |
| **IR proximity/distance sensor** | A sensor that detects how far away a reflective object (the opponent) is. | Your opponent-detection/tracking system feeding into the PID loop. |
| **False-trigger filtering** | Logic to reject sensor readings caused by glare, lighting, or unintended reflective surfaces rather than the real target. | Needed because the rulebook's arena has a **white painted frame** — a strong reflective surface your edge sensors must correctly interpret as "the boundary," not ignore or misread. |

---

## 5. Rulebook-Driven Design Constraints (things the terms above must work within)

| Constraint | Rule reference | Design implication |
|---|---|---|
| **Max weight: 3kg** | 4.1 | Every component choice (motors, wheels, battery, chassis material) must be weighed against this budget — this is why we favored lighter/cheaper options where torque/traction weren't compromised. |
| **Max footprint: 20×20cm** (no height limit) | 4.2 | Leaves you room to go tall if needed, but constrains wedge width and wheelbase. |
| **Controller must be Arduino Uno Q — no other primary microcontroller allowed** | 4.4 | **This overrides my earlier suggestion to use a Nano instead.** You must learn the Uno Q's specific I/O, PWM, and ADC behavior (it's a newer Linux-based SBC, not a classic AVR board) since your whole PID/sensor/motor-driver logic has to run on it specifically. |
| **Fully autonomous — no remote control** | 4.4 | Your decision loop (edge check → opponent check → PID drive) must run entirely onboard with no human input after activation. |
| **Front/wedge must not be white or a color that affects sensor readings** | 4.5 | Confirms your matte non-white wedge finish decision was correct — this is a hard rule, not just good practice. |
| **No magnets, suction, vacuum wheels, or adhesives** | 4.6 | Confirms your traction strategy must come entirely from wheel width/compound (like the 52×30mm silicone wheel), not from artificially anchoring to the floor. |
| **5-second mandatory stationary period after activation** | 6.2 | Your control loop must include a hard-coded 5-second delay before any movement — moving early is an explicit warning-triggering offense (7.3). |
| **3-minute round timer** | 6.7 | Your search-pattern/engagement logic needs to be effective within this window — long, cautious search patterns risk timing out without contact. |
| **Arena: 1.5m diameter, white 3cm frame, black surface** | 5.1 | Confirms your edge sensors are distinguishing black (safe) from the white frame boundary (edge) — directly relevant to the false-trigger filtering concept above. |

---

## 6. What to Actually Study (in priority order)

1. **DC motor fundamentals** — torque/speed/current relationships, stall vs. running behavior. Directly explains every number on your motor's datasheet.
2. **Basic mechanics (torque → force conversion, friction)** — lets you calculate push force and understand why wheel width matters more than raw torque once you're traction-limited.
3. **Arduino Uno Q specifics** — since it's a newer Linux-based board rather than a classic AVR Arduino, its GPIO/PWM/ADC handling may differ from typical tutorials. Worth reading its official documentation directly rather than assuming it behaves like an Uno R3.
4. **PID control basics** — enough to implement and then manually tune Kp/Ki/Kd on your actual robot.
5. **Power electronics basics** — capacitor sizing for brownout protection, how voltage regulators/BECs work.
6. **Sensor debouncing and filtering logic** — small but critical code patterns that prevent erratic behavior near contact.

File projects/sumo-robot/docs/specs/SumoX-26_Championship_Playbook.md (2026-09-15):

# SumoX-26 Championship Playbook
### A complete, beginner-to-advanced guide to building a winning autonomous sumo robot for the Dubai Techbots League (Besomi Academy × Arduino × Qualcomm × Canadian University Dubai)

> **How to use this guide:** It's written so you can start at zero knowledge in any subsystem (mechanics, electronics, or code) and build up. Each part starts with "what this even means" before getting technical. Read it top to bottom once, then use it as a checklist while you build. When you want to go deeper on any one section — motor math, sensor code, whatever — just ask, and we'll zoom in from there.

---

## PART 1 — The World of Robot Sumo (learn from the champions)

### 1.1 Where this sport comes from
Robot sumo isn't new — it's one of the oldest and most respected robotics sports in the world, and understanding its history tells you exactly what wins.

<cite index="5-1">Robot-Sumo began in Japan in 1989, when FUJISOFT Inc. organized an experimental robot-sumo tournament that became the All Japan Robot Sumo Tournament</cite>. Since 1998, <cite index="5-1">FUJISOFT has worked with more than 30 countries, and the sport has spread and become one of the most popular robotics competitions in the world.</cite> That tournament — the **All Japan Robot-Sumo Tournament (AJRST)** — is the closest thing this sport has to a World Championship, and it's held every December in Tokyo, gathering national champions from around the globe to fight for the international title.

The physical rules of that original Japanese competition are almost identical to yours: <cite index="6-1">a robot sumo win happens when the opponent robot touches the outside area of the ring, the robot must be designed only to push, and weapons or damaging devices are prohibited. Robot sumo must weigh 3 kg or less and measure 20 cm × 20 cm or less, with no height restriction.</cite> That means your event is running the exact same weight class as the world's top tournament — you're not in some watered-down junior version, you're building to the same spec real champions use.

### 1.2 Champions worth studying
- **Sakin (Turkey)** — <cite index="3-1">Sakin placed 2nd at the 2014 All Japan International Robot Sumo Tournament, a competition where the reigning three-year-unbeaten Japanese champion was defeated for the first time — then went on to win 1st place outright in 2015.</cite> Lesson: dethroning Japan is possible with disciplined engineering, not just budget.
- **Senju (Sumozade-Era Robotics, Turkey)** — recognized as the <cite index="7-1">first non-Japanese team to win the Mega Sumo Autonomous world title</cite>, a genuine underdog story.
- **ThundeRatz (Brazil)** — <cite index="7-1">dominated the RoboCore 3kg RC sumo class for years with their robot "Stonehenge," known for engineering discipline.</cite>
- **Georgia Tech RoboWrestling (USA)** — an active university team that <cite index="4-1">competes annually at the All Japan Robot-Sumo Tournament grand final, and is also building 3kg autonomous bots for regional qualifiers like RSM International in Brazil, which draws over 1,000 competitors.</cite>

### 1.3 Where the sport is growing right now
- **Japan** — still the historic center of gravity, but <cite index="7-1">in a notable 2025 shift, FUJISOFT pivoted focus toward the smaller 50g Mini Sumo class specifically to lower the barrier to entry and spark innovation in micro-robotics</cite> — a sign the sport is actively evolving.
- **Brazil** — <cite index="5-1">home to RoboCore, which ran the first official national robot-sumo tournament in Brazil in 2008, and became "the Brazilian National Robotics Championship" through the 2010s.</cite>
- **Turkey, Romania, China** — <cite index="7-1">Turkey and Romania both field strong competitive scenes, and China's RobotChallenge hosts large-scale championships as well.</cite>
- **UAE** — your event (Dubai Techbots League, backed by Besomi Academy, Arduino, and Qualcomm) is part of a fast-growing regional robotics scene alongside events like MBZIRC and the Emirates Robotics Competition — this is a young but serious ecosystem, and being early gives you a real shot at being a name people remember.

### 1.4 The one lesson every champion shares
Every write-up on elite sumo teams comes back to the same idea, and it's worth internalizing before you touch a screwdriver:

> **"Speed is life, but traction is god."** A fast, powerful robot that can't grip the floor is worthless. **Weight matters** — every one of your 3,000 grams should be doing a job. **Sensors are eyes** — a robot that can't see the opponent or the edge, no matter how strong, will lose or drive itself off the arena.

---

## PART 2 — Decoding Your Rulebook (in plain language)

Before building anything, let's translate the official terms into beginner language, because misunderstanding these costs teams matches.

| Rulebook term | What it actually means |
|---|---|
| **Round** | One single fight, up to 3 minutes. Whoever loses the pre-round coin-toss places their robot first. |
| **Match** | Best of 3 rounds (win 2 to take the match). If it's 1–1, a 3rd deciding round happens. |
| **Warning (yellow card)** | An official strike against your team for a rule slip-up. 6 warnings in the whole event = automatic disqualification. |
| **Violation (red card)** | An immediate, single disqualifying offense (e.g., intentionally damaging the opponent's robot). Forfeits all points and prize eligibility instantly. |

### 2.1 The numbers you must design around

| Spec | Limit | Why it matters |
|---|---|---|
| Weight | ≤ 3 kg | This is the classic "Mega Sumo" weight class used worldwide — every gram should add pushing power or control, not decoration. |
| Footprint | ≤ 20 cm × 20 cm | Measured at the **start** — no height limit at all, which is a real design opportunity (see §3.2). |
| Controller | **Arduino UNO Q — mandatory, no other primary microcontroller allowed** | This is unusual and a genuine advantage — more on this in Part 3. |
| Control mode | 100% autonomous — remote control is strictly banned | Your robot has to think for itself in real time. |
| Arena | 1.5 m diameter, circular, wooden, white 3 cm frame, black surface, two 20 cm brown centre lines | Know this surface — you'll calibrate your sensors against these exact colors. |
| Round timer | Max 3 minutes, starts after both robots have been stationary for 5 seconds post-whistle | Moving before the 5 seconds is literally a *listed cause for a warning*. |

### 2.2 The five rules that quietly decide matches (read these twice)
1. **Your front (blade/wedge) must NOT be white**, or any color that could interfere with sensor readings. This isn't cosmetic — the arena frame is white, so a white robot front risks confusing edge-detection logic (yours or the opponent's), and referees will flag it.
2. **No suction, vacuum wheels, magnets, or adhesives** to grip the arena — traction has to come from honest tire grip.
3. **No liquids, gases, powders, or projectiles** — pure pushing only.
4. **Size can change *after* the round starts**, as long as everything stays attached to the main body — this legally allows a "deployable" design (see §3.2).
5. **3 warnings in a single round = automatic loss of that round.** A detached part (even a small one) costs a warning *per part* unless it clearly didn't affect the match — so build things to stay attached.

---

## PART 3 — The Build: Step by Step

We'll go in the order you should actually build: **plan → mechanics → electronics → code → test.** Each step assumes you're new to that specific skill.

### STEP 1 — Design Planning & Weight Budget
**Beginner concept:** A "weight budget" just means deciding, on paper, how many of your 3,000 grams go to each part *before* you buy anything — so you don't build a great chassis and then discover there's no weight left for motors.

A reasonable starting budget for a 3 kg competitive bot:

| Component | Typical weight |
|---|---|
| Chassis + wedge front | 400–700 g |
| 2× drive motors + gearboxes | 300–600 g |
| Wheels + tires | 100–200 g |
| Arduino UNO Q + motor driver + wiring | 150–250 g |
| Battery (LiPo) | 150–300 g |
| Sensors (opponent + edge) | 50–100 g |
| Ballast (tungsten/steel weights, added last) | **remaining budget** |

That last row is deliberate — top teams always finish light and add **ballast** (extra weight) strategically at the very end, low and centered, to hit exactly 3.00 kg with the best possible weight distribution. Never design "to the limit" from the start.

### STEP 2 — Mechanical Design & Chassis
**Beginner concept:** "Center of gravity" (CG) is the average point where your robot's weight is balanced. A **low, centered CG** is the single biggest predictor of sumo success — it's why every serious sumo robot looks squat and heavy, never tall and top-loaded.

- **Chassis material:** Aluminum (6061-T6) is the gold standard — <cite index="29-1">strong, machinable, and dense enough to fill your weight budget efficiently. HDPE plastic works well for secondary, non-structural brackets, while thin acrylic should be avoided for structural parts because it shatters on impact.</cite>
- **Shape:** <cite index="29-1">A wider chassis resists being flipped sideways. Place your drive wheels near the outer edges of the frame for stability, and a 2-wheel differential drive with wheels toward the rear-center gives good maneuverability with a forward push bias.</cite>
- **The wedge/blade front:** The most common and effective mechanical trick in sumo robotics is a low-angled wedge at the front that <cite index="5-1">gets underneath the opponent to lift it slightly and make it easier to push</cite>. Remember: **not white, not a color that messes with sensors.** Matte black or a dark, non-reflective color is the safe, common choice.
- **The "no height limit" opportunity:** Since your rulebook only restricts the 20×20 cm footprint at rest and allows shape changes *after* movement begins, this is where a **deployable design** becomes a legal advantage — for example, side "wings" or a rear panel that flip open once movement starts to make you a harder target to flank, as long as everything stays attached to the body (rule 4.3). This is an advanced technique — get your basic robot working first, then consider this as an upgrade.
- **Wheels:** <cite index="22-1">Purpose-made silicone sumo wheels (like JSumo's) give the best grip, though modified toy-car wheels with added-friction surfaces are a valid budget option. Make sure the wheel's mounting hole matches your motor's output shaft diameter exactly.</cite>

### STEP 3 — Motors, Gearing & Wheels (the push power)
**Beginner concept:** *Torque* is rotational force (how hard the wheel can push against resistance); *speed* (RPM) is how fast it spins. A **gear ratio** trades one for the other — gearing down a motor makes it slower but much stronger, which is exactly what sumo needs.

- Sumo motors typically run at fairly high gear reduction, prioritizing torque over top speed — since the fight happens at close range, raw shove power usually beats speed. <cite index="26-1">Brushed DC motors with a gear ratio of roughly 10:1 or higher are the standard choice for high torque; brushless motors are also used by advanced teams for efficiency.</cite>
- Real-world example for your weight class: <cite index="29-1">for a 3 kg robot, two motors delivering roughly 8–10 kg·cm of torque each, driving 80–100 mm wheels, produces about 2–3 kg of usable push force — generally enough to overpower most opponents in this class.</cite>
- **A simple way to test if your motors are strong enough (no advanced math needed):** disconnect the wheels, hook a fish/luggage scale to the front of the finished robot, and slowly pull. The force reading at the moment it starts sliding tells you the minimum push force you need to beat — aim for your motors to comfortably exceed that.
- **Formula, if you want the actual math:** `Output torque = Motor torque × Gear ratio × Gearbox efficiency (usually ~80–90%)`. More gear stages = more torque but more heat and complexity — pick the *lowest* ratio that still clears your target with some margin.

### STEP 4 — Electronics: Building Around the Arduino UNO Q
This is the part that makes your competition genuinely different from older-style sumo events, so let's slow down here.

**What the UNO Q actually is (beginner explanation):** Most classic sumo robots use a simple microcontroller — a small chip that runs one program, reading sensors and driving motors, nothing else. Your rulebook mandates something much more powerful: <cite index="12-1">the UNO Q is Arduino's first Linux-capable board, combining a quad-core Qualcomm Dragonwing QRB2210 processor with GPU for AI and vision tasks, together with a dedicated STM32U585 real-time microcontroller — running Arduino sketches — on a single board.</cite> In plain terms: **it's two brains in one board.**

- **The "MCU" side (STM32)** behaves like a normal Arduino — this is what you'll use for the time-critical stuff: reading edge sensors and driving motors instantly, with no lag. <cite index="14-1">This side runs on Zephyr RTOS with the familiar Arduino core on top, so your sketches work as expected, and it handles real-time I/O with predictable, glitch-free timing.</cite>
- **The "MPU" side (Qualcomm chip)** runs a full Linux computer, capable of running a camera and lightweight AI models. <cite index="15-1">This lets you plug in a USB or CSI camera and use the board's AI engine for object detection or pattern recognition, right on the robot, with no cloud connection needed.</cite>
- **Why this matters competitively:** classic IR sensors can be fooled by black robots, weird angles, or bright arena lighting. A robot that uses the camera + AI side to visually identify "that's a robot, not the black floor" is a genuine, rules-legal edge over teams using only basic IR sensors — and it's exactly the kind of "edge AI" use case this board and its Qualcomm sponsor are built for. **This is an advanced upgrade path — build the reliable IR-sensor version first, get it competition-ready, then experiment with vision as a stretch goal.**

**Core electronics checklist:**
| Part | Beginner explanation | Notes |
|---|---|---|
| Arduino UNO Q | Your robot's brain (mandatory) | Program the MCU side with Arduino IDE/App Lab for real-time motor + sensor logic |
| Motor driver (H-bridge) | A "translator" that lets a low-power signal from the Arduino control a high-power motor safely | Choose one rated for at least your motors' stall current |
| Battery | Power source | LiPo (lithium polymer) is standard — <cite index="22-1">high power for its size, commonly used in the 2–3 cell (7.4–11.1V) range for 12V-class motors</cite> |
| Opponent sensors (2–4x) | "Eyes" that detect the other robot | <cite index="27-1">Infrared or ultrasonic sensors both work — infrared/modulated light sensors generally have faster response times</cite>. Mount facing outward, covering front and sides |
| Edge sensors (4x minimum) | "Eyes" that detect the white boundary line so you don't drive off | <cite index="29-1">Place a minimum of 2 front and 2 rear sensors at the corners of the chassis so contact from any direction is caught — 4 total is standard, some teams add 2 more on the sides for full coverage</cite> |

### STEP 5 — Programming: Giving Your Robot a Brain
**Beginner concept:** Nearly every winning sumo robot — regardless of country or era — runs the same basic decision loop, called a **state machine**: a simple "if this happens, do that" flow with only a few possible modes.

Here's the logic in plain pseudocode before you write real code:

```
SETUP:
  wait for start signal (whistle / start module)
  stay still for 5 seconds  ← rule 6.2, moving early = warning

LOOP forever:
  1. Check edge sensors FIRST, always, on every single cycle
     → if any edge sensor detects the white line:
         stop, reverse briefly, turn away from that edge
         go back to step 1

  2. Check opponent sensors
     → if opponent detected:
         turn to face it, drive forward at full power (ATTACK)
     → if opponent NOT detected:
         rotate slowly in a search pattern (SEARCH)
         e.g. spin in place, or arc in a circle scanning outward

  3. repeat
```

<cite index="42-1">Some teams vary their start routine — for example turning 45° to one side before charging forward — specifically so an opponent can't pre-program a counter-attack against a predictable straight-line start.</cite> This is worth doing once your base logic works.

**Tuning tips from experienced builders:**
- <cite index="30-1">Calibrate edge sensor thresholds carefully — this is the single most common cause of accidentally driving off the arena.</cite>
- <cite index="26-1">If your reactions feel sluggish, your control loop code is likely too slow — simplify your logic and use interrupts for sensor reads rather than constantly polling in the main loop.</cite>
- Always check edge sensors *before* opponent sensors in your code, every single loop — a robot that's mid-attack but ignores the edge will drive itself out and lose instantly.

### STEP 6 — Testing & Practice
- Test on a surface as close to the real dohyo as possible — <cite index="29-1">different floor textures change traction dramatically, so borrow or replicate a sample of the black arena surface if you can.</cite>
- <cite index="29-1">Always bring two fully charged battery packs and 5+ spare fuses — motor stall current can blow fuses mid-event.</cite>
- <cite index="29-1">Weigh your robot before every single match — teams sometimes add last-minute ballast and accidentally go over the 3 kg limit.</cite>
- Run at least 20–30 full mock matches against a practice opponent (even a cardboard-weighted box on wheels) before competition day — most bugs only show up under real contact forces, not on a workbench.

---

## PART 4 — Competition Day Playbook

### 4.1 Team roles (per your rulebook)
- **2–3 members**, one designated **Team Leader** (talks to referees, runs team logistics)
- One **Team Supervisor**, locked in for the whole event — choose this person carefully, they can't be swapped later
- **Only one member may place/activate the robot per round** — decide in advance who that is and practice the placement + activation + step-away sequence so it's fast and clean

### 4.2 A warnings/violations checklist — don't lose the event to a rules mistake
| Avoid this | Why |
|---|---|
| Moving before 5 seconds after the whistle | Explicitly listed as a warning cause |
| Anyone approaching the robot/arena mid-round | Can cost you the round outright |
| A white or reflective front/blade | Warning risk + possible referee rejection at inspection |
| Loose screws/parts that could detach | 1 warning per detached part |
| Any last-second component swap after inspection | Can mean disqualification |
| Arriving late | More than 1 minute late forfeits the round; late twice in a row can forfeit the whole match |

Remember: **6 total warnings = automatic disqualification**, and if a tiebreaker is ever needed, "fewest warnings" is literally the first tiebreak criterion in Section 9. Clean play isn't just good sportsmanship here — it's a direct scoring advantage.

### 4.3 Referee & sportsmanship notes
- Treat the referee's calls as final in the moment — the rulebook gives them wide discretion (stopping/suspending rounds, judging what counts as "disruption," etc.)
- The tiebreak criteria (Section 9) explicitly reward **robot design/engineering quality** and **consistent, deliberate, non-random movement** — so a robot that visibly "knows what it's doing" (not just spinning randomly) is scored better even outside of pure wins.

---

## PART 5 — The Winning Formula (cheat-sheet summary)

1. **Weight-budget everything** — every gram of your 3 kg should do a job; finish under-weight and add ballast low and centered.
2. **Low, wide, centered chassis** beats tall and narrow, every time.
3. **Torque over top speed** — you're fighting at point-blank range in a 1.5 m ring, not racing.
4. **Edge sensors always win the priority check** in your code — check them before anything else, every loop.
5. **Never use a white or reflective front.**
6. **Use the UNO Q's dual-brain design as your edge** — reliable real-time IR-based logic first, camera/AI vision as your stretch goal.
7. **Practice your start routine and vary it** — predictability loses to teams who scout you.
8. **Zero warnings is a real strategic goal**, not just good manners — it's your tiebreaker insurance.

---

## PART 6 — Suggested Learning Roadmap (if you're starting from scratch)

| Week | Focus | Outcome |
|---|---|---|
| 1 | Rulebook mastery + design sketch + weight budget | A drawn/CAD concept and parts list |
| 2 | Chassis build + motor/wheel mounting | A rolling, driveable (manually wired) base |
| 3 | Arduino UNO Q basics — blink an LED, read a sensor, drive a motor via code | Comfort with the dev environment |
| 4 | Wire up opponent + edge sensors, calibrate thresholds | Reliable sensor readings on the real arena colors |
| 5 | Write and test the search → attack → edge-avoid state machine | A robot that survives on its own for a full round |
| 6 | Practice matches, tune motor speeds/turn angles, weigh & finalize | Competition-ready robot |
| 7+ | Stretch goal: camera-based opponent detection on the MPU side | Extra edge over IR-only competitors |

---

*This guide is based on your official SumoX-26 rulebook plus current (2026) research on world sumo robot competitions, engineering practices, and the Arduino UNO Q platform. Ask anytime you want to go deeper on a specific part — motor math, wiring diagrams, or actual starter code — and we'll build it out from wherever you are right now.*

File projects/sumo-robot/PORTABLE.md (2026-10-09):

# PORTABLE CONTEXT: sumo-robot
Generated 2026-10-09 by scripts/build_portable.py. Read-only copy; the source of truth is STATE.md / LOG.md in the repo.
Rule: if you cannot open a link below, say so and ask me to paste it. Never claim to have read what you could not open.
If you cannot write files, give me log lines and STATE edits as text to paste.

## Who
Shreyank, 2nd-year Mechatronics Engineering student (UOWD). Goal: quantitative finance (discretionary trading + systematic/quant development). This repo is a public log of everything he learns, builds and earns.

## Rules for AI
1. Read `AI-CONTEXT.md`, then `projects/<X>/STATE.md`. Open code files only when the task needs them. To find code, read `scripts/codemap/CODEMAP.md` first (auto-generated functions/classes per file with line numbers; trust names, line numbers may lag; outside the MCP open `https://raw.githubusercontent.com/Shreyankkkkk/foundations/main/scripts/codemap/CODEMAP.md`).
2. Constants: never invent or hard-code. Every constant gets its calculation or measurement shown beside it, plus the source. Unmeasured = say so, mark it `PLACEHOLDER`; assumed = `ASSUMED`.
3. Code changes: give the code and say which file and where in it the change goes (he does not know the file layout by heart).
4. Be token-efficient: no padding.
5. Never run git commit/push. Shreyank commits. Before big edits, remind him to commit first.
6. Use today's date for every log line; never guess a date. If a date is unknown, write `date?`.
7. Naming: lowercase kebab-case, no spaces, `exercises` (not excercises). Do not create empty folders. Every folder with real content gets a README.
8. Public repo: no passwords, tokens, ID numbers, personal finances or private chat content.
9. Tokens: never read a whole `LOG.md` or journal file; read the last 3 lines only (tail). To append a line, use `edit_file` with the last line as `oldText` and that line plus the new line as `newText`. Never rewrite a whole file with `write_file` when a few lines change. Log only when he says `log it`, not after every message. To find or read part of a file, use `search_code` and `read_lines` (foundations-helper MCP) instead of opening whole files; if they are not listed, use the filesystem tools.
10. Teaching notes: when he asks to learn a term or topic, reply with the note content only, in one code block, template: Definition / Why it matters (for the project) / How it works / Example / 3 self-test questions. Max 200 words per term, plain language first. He pastes it into the right file himself: do not create, edit or re-read note files unless asked. Project notes go in `projects/<slug>/notes/`; reusable ones in `learning/<area>/notes/`.
11. If you cannot open a file or link, say so and ask him to paste it. Never claim to have read something you could not open. Outside the MCP, open raw file URLs (`raw.githubusercontent.com/...`), not GitHub directory pages.
12. `STATE.md` stays under about 150 lines and holds current truth only; history belongs in `LOG.md`. `projects/*/PORTABLE.md` is generated by `scripts/build_portable.py`: never edit it by hand.

## How to log (three layers, end of every session)
1. `journal/YYYY-MM.md`: append one line per session: `YYYY-MM-DD | learn/build/plan/research/achieve | what | files`.
2. Project work only: also append the detailed line to that project's `LOG.md`: `YYYY-MM-DD | what changed | why | evidence (file path or commit)`.
3. If the project's truth changed (a constant, a decision, a status): update its `STATE.md`. If a certificate was earned: add a row to `certificates/README.md`.
Newest at the bottom. One line per entry, however small. List changed files in the reply.

---

## STATE (sumo-robot)

# Sumo-Robot STATE (SumoX-26, TechBots League Dubai)

Status: finished. Eliminated after the first 3 matches (2026-10-04). Retrospective: `Retrospective.md`.
Controller: Arduino UNO Q (sole controller, fully autonomous, max 20x20 cm / 3 kg).
Code that was on the board: `firmware/strategy/v2.4_Strategy/`.
Full history: `LOG.md`. Raw per-chat summaries: `notes/chat-summaries/`.

## Result
| Match | Outcome |
|---|---|
| 1 | skipped, wiring not finished |
| 2 | stalemate, won coin flip (wiring still not finished) |
| 3 | stalemate, lost coin flip, eliminated (wiring still not finished) |

Causes: (1) the whole competition day went on wiring and it was never completed; (2) the robot sat so low that opponents' sensors could not detect it.
v2.4 and every motion constant below were never tested on the real robot (no time).

## Version map (folders in `firmware/strategy/`; name used in chats)
| Folder | Chat name | What it is |
|---|---|---|
| v1.0_Strategy | 1_strategy | first strategy split: Strategy_1/2 files only |
| v1.1_Strategy | 2_strategy | first full modular sketch: Hardware, Motors, Robot, Sensors + Strategy_1/2 |
| v1.2_Strategy | 3_strategy ("v3") | Hybrid: Strategy 1 P-control + side-override debounce, hammer attack, start palette |
| v1.3_Strategy | 4_strategy ("v4") | Strategy_Ram: 3 opponent + 2 edge sensors, Search/Align/Commit, dead-reckoned heading |
| v2.0_Strategy, v2.1_Strategy | 5_strategy ("v5") | map-based: ram at t=5 s, center-anchored position map, 6 files |
| v2.2 / v2.3 / v2.4 | created on the last day | v2.2 = start-flow + spin-sign fixes; v2.3 = ADC median, slew limiter, re-arm; v2.4 = Hardware.h/Formulas.h split, auto edge polarity |

## Hardware (as built)
- 3x GP2Y0A21 opponent sensors (front, left/right at 45 degrees), through 10k/10k dividers (A0-A2)
- 2x TCRT5000 edge sensors (front D10, back D11), mounting height band ~1.5-3 cm
- 2x BTS7960 drivers, 2x Titan 12V 200 RPM motors, coaxial as built (initial plan was staggered), 2x JS5230 52x30 mm wheels + 2 idlers
- UBEC steps 5V down to 3.3V for the board; sensors on 5V; KCD4 main switch cuts battery; start trigger = latching rocker on A4
- Black matte PETG detachable wedge, very low ground clearance
- Power as bought per chats: 35 A fuse, one 2200 uF cap on the motor bus, 470 uF on the UBEC 5 V rail, 8x 10k resistors for dividers
- Battery: 3S nominal 11.1 V (3 x 3.7), full 12.6 V (3 x 4.2); cell type never settled in the summaries (18650 holder vs LiPo): UNCONFIRMED
- KCD4 switch DC rating never confirmed (listing gives 16 A / 250 VAC only; load ~8.2 A stall): UNCONFIRMED
- Files: `docs/specs/final_wiring.md` (materials.xlsx is not in the repo)

## Rulebook limits used in code and design
| Rule | Value | Where used |
|---|---|---|
| 4.1 / 4.2 | 3 kg, 20x20 cm, no height limit | chassis, ROBOT_* geometry |
| 4.4 | UNO Q sole controller, fully autonomous | whole design |
| 4.5 | front must not be white | chassis finish |
| 4.7 / 6.11 | no changes after inspection | flash final build; detachable wedge needs referee OK |
| 5.1 / 5.2 | ring 150 cm, 3 cm white border, 2 brown lines 2 cm x <=20 cm, 10 cm from center | arena constants, start pose |
| 6.2 / 7.3 | 5 s stationary or warning; 3 warnings lose a round, 6 = DQ | START_COUNTDOWN_MS |
| 6.6B | no touching the robot mid-round | switch OFF only after round ends |
| 6.6D | referee stops a stuck robot after 30 s | STALEMATE_HARD_CEILING_MS |
| 9 | 25-30 cm safety zone; tie-break prefers non-random movement | SAFETY_ZONE_MIN_CM, random opening move removed in v5 |

## Constants (value | calculation or measurement | source | status)
Rulebook
| Constant | Value | Calculation / measurement | Source | Status |
|---|---|---|---|---|
| ARENA_RADIUS_CM | 72 | (150 - 2x3)/2 | rulebook s5.1, Formulas.h | derived |
| ARENA_OUT_RADIUS_CM | 75 | 150/2 | rulebook s5.1 | derived |
| START_COUNTDOWN_MS | 5050 | 5000 mandatory delay + 50 margin | rulebook, Hardware.h | derived |

Robot geometry (ruler)
| Constant | Value | Calculation / measurement | Source | Status |
|---|---|---|---|---|
| WEDGE_TO_FRONT_SENSOR_CM | 4.7 | ruler | Hardware.h | measured |
| REAR_TO_BACK_SENSOR_CM | 3.6 | ruler | Hardware.h | measured |
| ROBOT_LENGTH_CM / ROBOT_WIDTH_CM | 20 / 20 | marked MEASURE in code; equals rule maximum | Hardware.h | UNCONFIRMED |
| REAR_TO_AXLE_CM | 3.6 | marked MEASURE; equals rear-to-back-sensor value. One axle line is valid (motors coaxial) | Hardware.h | value UNCONFIRMED |
| ROBOT_L_F_CM | 16.4 | 20 - 3.6 | Formulas.h | derived |
| START_POSE_RADIUS_CM | 27.4 | 11 + 16.4 | Formulas.h | derived |
| ROBOT_R_SWING_CM | 19.21 | max(hypot(10,16.4), hypot(10,3.6)) | Formulas.h | derived |
| OPEN_SWEEP_HALF_ANGLE_DEG | 35.5 | atan(20/(2x11+16.4)) + 8 deg aim error = 27.5 + 8 | Formulas.h | derived |
| EDGE_SENSOR_FRONT_OFFSET_CM | 11.7 | L_F - 4.7 = 16.4 - 4.7 | Formulas.h | derived |
| Chassis STL (first design) | 200.006 x 200.008 x 73.17 mm | trimesh bounding box; zero margin to the 200 mm cap | Final_Sumo_Robot.stl | measured (design file, not final print) |

Drivetrain and mass (derived from vendor specs; none measured on the robot)
| Constant | Value | Calculation | Source | Status |
|---|---|---|---|---|
| Wheel circumference | 163.4 mm | pi x 52 mm | JS5230 listing | derived |
| Wheel speed | 3.333 rev/s | 200 RPM / 60 | Titan listing | derived (vendor RPM) |
| Free-run top speed | 54.45 cm/s | 163.4 mm x 3.333 | A1-10, A1-16 | derived upper bound |
| Top speed at 12.6 V | 57.2 cm/s | 54.45 x 12.6/12 | A1-16 | derived (linear-in-voltage assumed) |
| Stall torque per motor | 1.015 N·m | 10.35 kg-cm x 0.0980665 | vendor | derived (vendor figure) |
| Stall current | 4.1 A each, ~8.2 A both | vendor; 2 x 4.1 | vendor | vendor / derived |
| Max wheel force | 78 N | 2.03 N·m / 0.026 m | A1-10 | derived (stall, upper bound) |
| Friction force at 3 kg, mu 0.6 | 17.7 N | 0.6 x 3 x 9.81 | A1-17 | derived from PLACEHOLDER mu |
| Free-run turn rate | 312 deg/s | omega = 2v/L = 2 x 0.5445 / 0.20 = 5.445 rad/s | A2-13 | derived upper bound (L = 20 cm ASSUMED) |
| Turn rate, 194 mm track variant | 321.7 deg/s | 2 x 0.5445 / 0.194 | A2-12 | derived (track from user figure) |
| Turn rate at PWM p | 312 x p/255 | 0.1835 deg/ms at PWM 150, 0.208 at 170 | A2-13 | derived (linear PWM scaling ASSUMED) |
| Non-chassis mass | ~939 g | 48+180+25+360+60+100+30+30+8+10+50+18+20 | A1-01 | PLACEHOLDER (mostly typical estimates; no weigh-in recorded) |

Electrical (from chats)
| Constant | Value | Calculation / measurement | Source | Status |
|---|---|---|---|---|
| UNO Q VIN range | 7-24 V | Arduino docs | docs | vendor |
| Divider ratio | 0.5 | 9.9k/(9.9k+9.9k), multimeter | Hardware.h | measured |
| GP2Y peak through divider | ~480 counts | 3.1 V x 0.5 = 1.55 V; 1.55/3.3 x 1023 | A1-17 | derived (3.1 V peak ASSUMED, datasheet not fetched) |
| START_SWITCH_ON_ADC | 775 | 2.5 V/3.3 V x 1023 | Hardware.h | derived |
| START_SWITCH_THRESHOLD_ADC | 387 | 775/2 | Hardware.h | derived |
| TCRT5000 HIGH through 10k/10k | 2.5 V | 5 x 10k/(10k+10k) | A1-14 | derived |

Sensors
| Constant | Value | Calculation / measurement | Source | Status |
|---|---|---|---|---|
| SENSOR_DIVIDER_RATIO | 0.5 | 9.9k/(9.9k+9.9k), multimeter | Hardware.h | measured |
| BENCH_NO_OBJECT_MAX | 100 | bench ADC, no divider | Hardware.h | measured (pre-divider) |
| BENCH contact / peak bands | 250-350 / 600-700 | bench ADC, no divider | Hardware.h | measured (pre-divider) |
| TCRT5000 height window | 1.5-3 cm | white HIGH (~1015), black LOW (0); below 1.5 cm both HIGH; above 3 cm both LOW | A1-14, A2-10 | measured (lit room; brown never tested on the real arena) |
| WEAK_THRESHOLD | 75 | 100 x 0.5 x 1.5 | Formulas.h | derived |
| CONTACT band | 125-175 | bench x 0.5 | Formulas.h | derived, never measured through dividers |
| PEAK band | 300-350 | bench x 0.5 | Formulas.h | derived, never measured through dividers |
| ADC_NOISE_SIGMA | 20 | none | Hardware.h | PLACEHOLDER |
| SENSOR_SAMPLE_INTERVAL_MS | 15 | ceil((38.3 - 9.6)/2), datasheet refresh 38.3 +/- 9.6 ms | Formulas.h | derived |
| WEAK_CONFIRM_SAMPLES | 4 | ceil((38.3 + 9.6)/15) | Formulas.h | derived |
| ADC_OVERSAMPLE_N | 7 | (20 / (50/6))^2 = 5.76, rounded up to odd | A1-17 | derived from PLACEHOLDER sigma |

Motion (never tested on the robot)
| Constant | Value | Needed measurement | Status |
|---|---|---|---|
| DRIVE_SPEED_MAX_CMS | 45 | distance / time at PWM 255 | PLACEHOLDER |
| SPIN_RATE_CW/CCW_DEGS | 120 | stopwatch spin test | PLACEHOLDER |
| STOP_DISTANCE_CM | 16 | slide after cutting power at full speed | PLACEHOLDER |
| FRICTION_MU | 0.6 | spring-scale pull / weight | PLACEHOLDER |
| MIN_MOVE_PWM | 90 | lowest PWM that moves loaded robot | PLACEHOLDER |
| DRIVE_DECEL_CMS2 | 63.3 | v^2/(2d) = 45^2/(2x16) | derived from placeholders |
| COMMIT_SOFT_START_S | 0.0765 | v/(mu x g) = 45/(0.6 x 981) | derived from placeholders |
| MOTOR_SLEW_PWM_PER_MS | 3.34 | 255/(0.0765 x 1000) | derived from placeholders |

Values that changed between versions (check before trusting any old number)
| Constant | History | Why it moved |
|---|---|---|
| START_COUNTDOWN_MS | 5200 (v3 Hybrid) > 5000 (v4) > 4850 (early v5, boot-based) > 5050 (v2.2+) | 5 s rule + margin; boot-based timing broke the rule |
| ADC resolution | 10-bit > 12-bit (one rewrite) > 10-bit | divider loss vs verified behaviour; never confirmed on UNO Q |
| Opponent divider | 10k/10k (0.5) > 10k/22k (0.688) discussed > 9.9k/9.9k measured | installed value was unknown for a while |
| DIST_THRESHOLD | 400 > 100 | divider halves the ADC scale |
| SENSOR_PEAK | 960 > 220 | same; the 220 arithmetic was flagged as possibly ~2x low (recomputed 387-480), not resolved |
| DETECT / ENGAGE (v4) | 150/550 > 150/480 > 100/465 | bench bands 250-350 and 600-700; idle reads 80-90 |
| TURN_RATE_DEG_PER_MS | 0.18 > 0.216 (no calc shown) > 0.312 (derived above) | 0.312 is a free-run upper bound |
| Arena diameter in BlindSumo | 100 cm (placeholder) vs 150 cm rulebook | conflicting statements, never settled; blind sketch constants unreliable |

## Strategy summary (v2.4)
5 ms loop: stop switch > edge sensors > strategy > motors > map update. States: OPEN_SWEEP, SEARCH, ALIGN, COMMIT, RETURN, STALEMATE_BREAK. Dead-reckoning map with uncertainty limits speed so the robot can stop before the rim. Detail: `firmware/strategy/CodeGuide.md` (OUTDATED). Fallbacks that existed: v4 (Strategy_Ram, v1.3) and BlindSumo (sensor-free, timed).

## Lessons
- Very low ground clearance meant opponents' sensors could not see the robot. Check ground clearance against typical opponent sensor height at design time.
- Wiring is the critical path: finish and test it days before the event, not on the day.
- Untested constants make the strategy unverifiable: bench-test motion constants early.
- Full lessons by stage: `Retrospective.md`.

## Where things are
- Strategy code: `firmware/strategy/v1.0_Strategy` ... `v2.4_Strategy`
- Tests/calibration sketches: `firmware/tests/` (GP2Y0A21, TCRT5000, Calibrate, Motor_Sensor, robot_testing)
- CAD: `design/` (`cad-v1`, `cad-v2`, `parametric`)
- Docs: `docs/specs/`, rulebook PDF in `docs/rulebook/`
- Notes: `notes/` (scans in `notes/scans/`); chat summaries and index: `notes/chat-summaries/`

## TODO
- Clean up `v2.4_Strategy` (unnecessary lines; user estimates 300+). Keep the original, work on a copy.
- Update or archive `firmware/strategy/CodeGuide.md` to match the clean-up
- Confirm real dates for the 33 backfilled chats (`notes/chat-summaries/INDEX.md`), then move them into dated LOG lines

---

## LOG (last 10 entries)

2026-09-24 | scanned handwritten pages | design/calibration notes | notes/scans/2026-09-24-scan.pdf
2026-09-25 | scanned notes + 6 design photos; first sensor calibration sketches | design v2 body + GP2Y0A21 calibration | notes/scans/2026-09-25-scan.pdf, design/cad-v2/, firmware/tests/
2026-09-26 | parametric CAD for front wedge and main deck | wedge/deck geometry from code | design/parametric/front_wedge_PARAMETRIC_SOURCE.py, main_deck_PARAMETRIC_SOURCE.py
2026-09-30 | scanned notes | TODO describe | notes/scans/2026-09-30-scan.pdf
2026-10-0? (last day before the event) | created v2.2, v2.3, v2.4 and renamed all versions from N_strategy to vX.Y | final strategy iterations | firmware/strategy/v2.2_Strategy ... v2.4_Strategy
2026-10-04 | competition: match 1 skipped (wiring not done); match 2 stalemate, won coin flip; match 3 stalemate, lost coin flip, eliminated | wiring never finished; robot too low for opponent sensors to detect; v2.4 and motion constants never tested | projects/sumo-robot/STATE.md
2026-10-04 | set up MCP logging for the repo (AI-CONTEXT.md, STATE.md, LOG.md) | cut tokens per chat, keep proof of work | AI-CONTEXT.md
2026-10-06 | backfilled this log from 33 chat summaries (18 from account 1, 15 from account 2); extended STATE.md constants; wrote Retrospective.md; added chat index | prove the work, build the project template | notes/chat-summaries/INDEX.md, Retrospective.md
2026-10-06 | restructured the repo: folders lowercased and regrouped (learning/, projects/, certificates/, journal/, _local/); Sumo split into docs/, design/, firmware/, notes/ | professional learning-log layout | README.md, AI-CONTEXT.md

---

## Other files (open only if the task needs them)

- https://raw.githubusercontent.com/Shreyankkkkk/quant-foundations/main/projects/sumo-robot/docs/specs/final_wiring.md
- https://raw.githubusercontent.com/Shreyankkkkk/quant-foundations/main/projects/sumo-robot/docs/specs/SumoX-26_Championship_Playbook.md
- https://raw.githubusercontent.com/Shreyankkkkk/quant-foundations/main/projects/sumo-robot/docs/specs/SumoX-26_Final_Strategies_v1_v2_v3.md
- https://raw.githubusercontent.com/Shreyankkkkk/quant-foundations/main/projects/sumo-robot/docs/specs/SumoX-26_Key_Terms_and_Design_Reference.md
- https://raw.githubusercontent.com/Shreyankkkkk/quant-foundations/main/projects/sumo-robot/docs/specs/SumoX-26_Stratgies.md
- https://raw.githubusercontent.com/Shreyankkkkk/quant-foundations/main/projects/sumo-robot/docs/specs/SumoX-26_Team_Prompt_Brief.md
- https://raw.githubusercontent.com/Shreyankkkkk/quant-foundations/main/projects/sumo-robot/docs/specs/SumoX-26_Wiring.md
- https://raw.githubusercontent.com/Shreyankkkkk/quant-foundations/main/projects/sumo-robot/docs/specs/wiring_reference.md
- https://raw.githubusercontent.com/Shreyankkkkk/quant-foundations/main/projects/sumo-robot/notes/chat-summaries/account-1-context.txt
- https://raw.githubusercontent.com/Shreyankkkkk/quant-foundations/main/projects/sumo-robot/notes/chat-summaries/account-2-context.txt
- https://raw.githubusercontent.com/Shreyankkkkk/quant-foundations/main/projects/sumo-robot/notes/chat-summaries/INDEX.md
- https://raw.githubusercontent.com/Shreyankkkkk/quant-foundations/main/projects/sumo-robot/notes/notes_1_brief.md
- https://raw.githubusercontent.com/Shreyankkkkk/quant-foundations/main/projects/sumo-robot/notes/notes_1_extended.txt

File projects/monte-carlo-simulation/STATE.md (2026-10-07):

# Monte Carlo Simulation STATE

Status: active. Python trading simulation. Goal: realistic prop-firm / trading-account outcome simulation; plan to publish as a website (TODO confirm).

## Versions in repo
- `archive/`: own iterations `monte_carlo_v1.0.0.py` to `v6.0.0.py`, plus `monte_carlo_chatgpt_v6.0.0.py` and `monte_carlo_claude_v6.0.0 / v6.1.0 / v6.2.0.py` (AI-written comparison versions)
- `current/`: modular version (was `ai-refactored-monte-carlo/`). Files: `main.py` (entry), `simulation_core.py` (Numba JIT single run), `orchestrator.py` (joblib parallel + aggregation), `metrics.py`, `plotting.py`, `config.py`, `database.py` + `schema.sql` (optional MySQL), `test_metrics.py`. Its `README.md` lists what changed from v1.

## Features (from the refactor README)
O(1) rolling-peak drawdown, all-core parallelism, cached JIT, fractional Kelly sizing, AR(1) trade correlation, GARCH(1,1) volatility clustering, psychological drawdown drift, session effects (London/NY/Overlap), partial profit-taking, Calmar ratio, 6-panel dark dashboard, pytest unit tests.

## Model parameters (value | justification | status)
| Parameter | Value | Justification given | Status |
|---|---|---|---|
| GARCH omega, alpha, beta | 0.00001, 0.09, 0.90 | "tuned for intraday returns" (README), no derivation shown | TODO: derive or fit from real data |
| Kelly fraction default | 0.25 | standard quant practice, Thorp (2006) | convention, not calibrated |
| AR(1) rho default | 0.0 (suggested 0.10-0.20) | README note | ASSUMED |

## Known issues / TODO
- Shorten the repo layout mismatch: README says `monte_carlo_pro/` and `tests/` but files sit flat in `current/`
- `__pycache__` was committed in `current/` (now gitignored); if it is still tracked, run `git rm -r --cached projects/monte-carlo-simulation/current/__pycache__`
- Calibrate parameters against real trade data from the trading journal
- Publish as a website (plan)

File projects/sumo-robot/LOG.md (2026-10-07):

# Sumo-Robot LOG

Format: `date | what changed | why | evidence`. Newest at the bottom. Add backfilled entries in date order.
Path map (folders renamed 2026-10-06; entries below may use the old names): `Strategy/` = `firmware/strategy/`; `tests/Code/` = `firmware/tests/`; `tests/Design/` = `design/parametric/`; `Design/1_Design`, `Design/2_Design` = `design/cad-v1`, `design/cad-v2`; `Details/markdown/` = `docs/specs/`; `Details/pdfs/` = `docs/rulebook/` (scans moved to `notes/scans/`); `Notes/` = `notes/`.
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

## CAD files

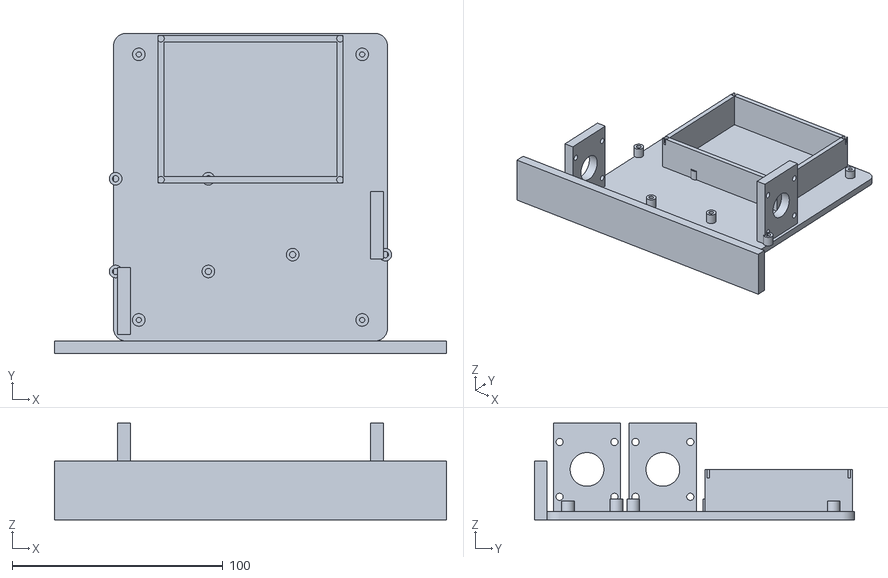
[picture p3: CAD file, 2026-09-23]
projects/sumo-robot/design/parametric/main_deck.stl
186.0 x 152.0 x 46.0

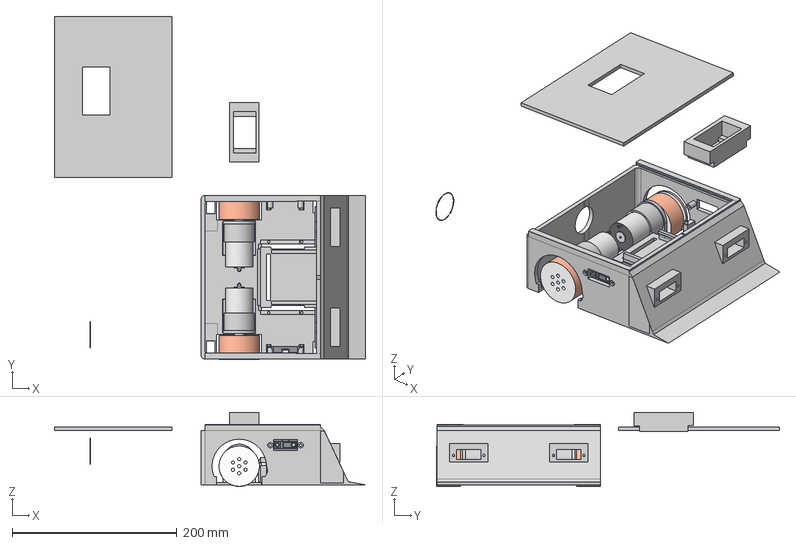
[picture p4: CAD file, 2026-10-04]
projects/sumo-robot/design/cad-v2/Sumo body v4.step
378.1 x 417.0 x 90.0 mm
Titan-37mm-500rpm
37 mm Motor Clamp for E & C

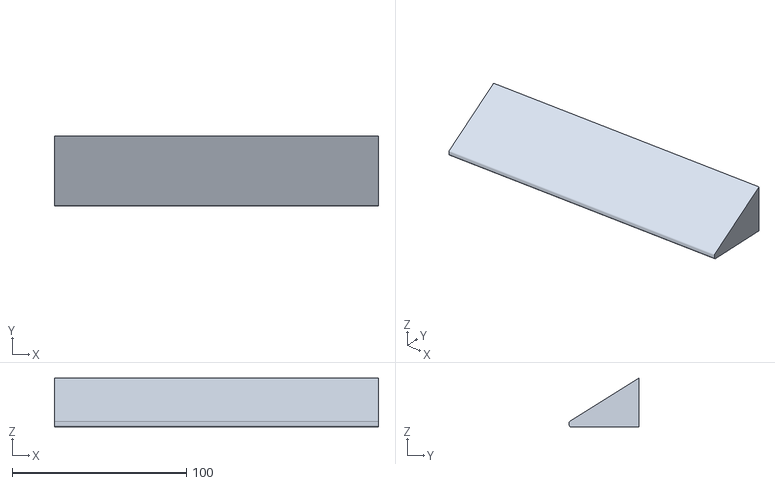
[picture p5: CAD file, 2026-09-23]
projects/sumo-robot/design/parametric/front_wedge.stl
186.0 x 40.0 x 28.0

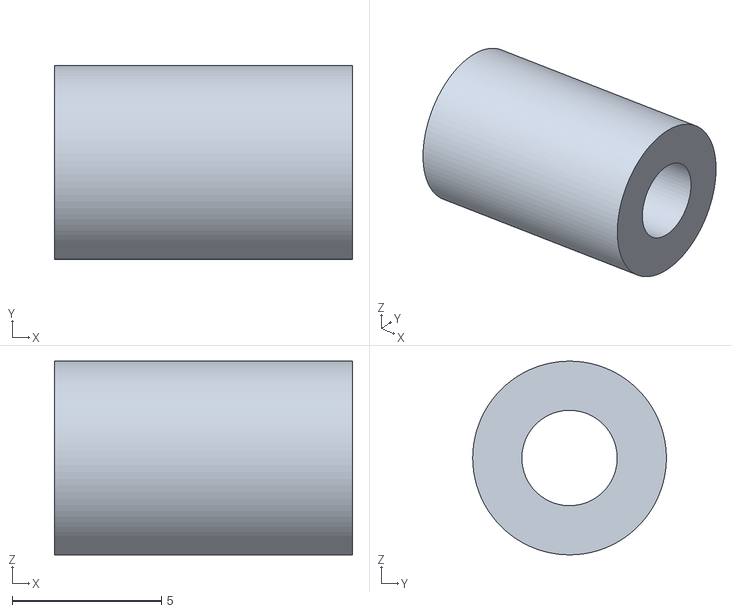
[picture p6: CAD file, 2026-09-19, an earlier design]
projects/sumo-robot/design/cad-v1/Robot_cylinder.stl
10.0 x 6.50 x 6.50

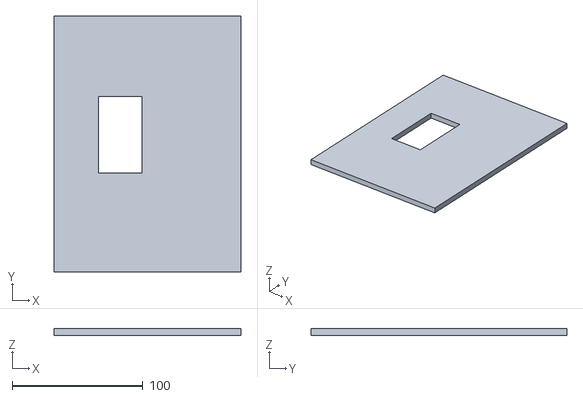
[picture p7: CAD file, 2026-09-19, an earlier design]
projects/sumo-robot/design/cad-v1/robot_detachable_roof.stl
143.0 x 195.5 x 5.10

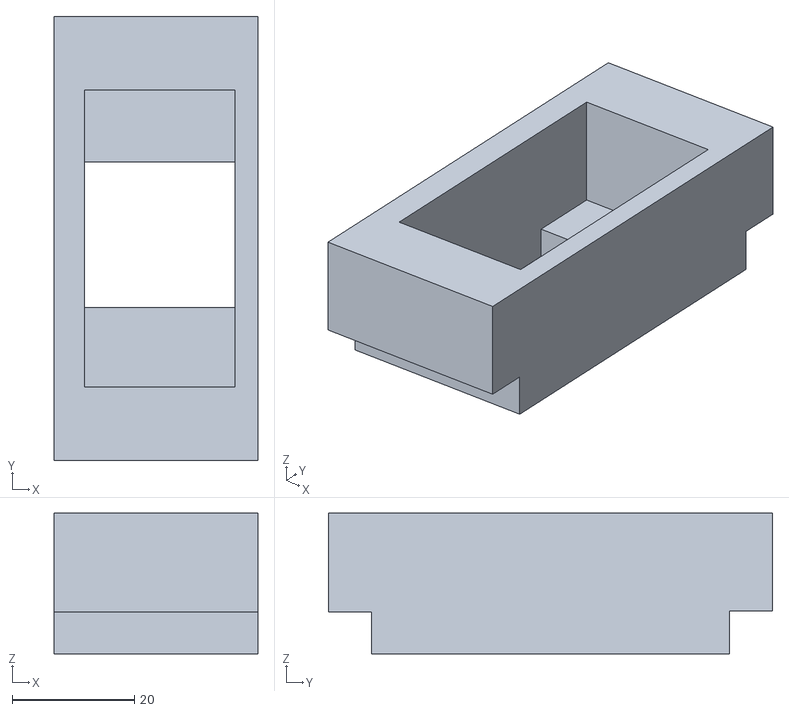
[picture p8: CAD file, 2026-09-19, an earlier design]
projects/sumo-robot/design/cad-v1/robot_switch_mount.stl
33.3 x 72.5 x 23.0

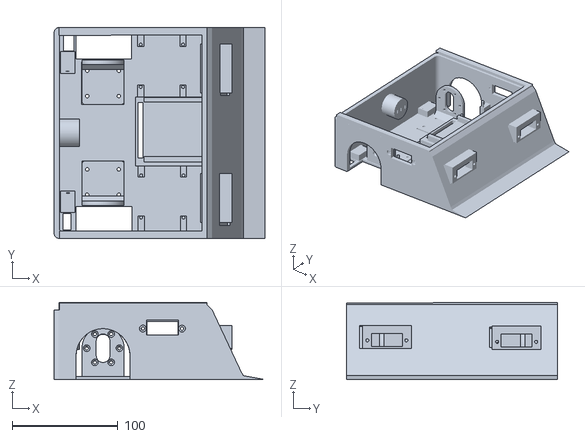
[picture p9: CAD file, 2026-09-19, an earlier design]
projects/sumo-robot/design/cad-v1/Final_Sumo_Robot.stl
200.0 x 200.0 x 73.2

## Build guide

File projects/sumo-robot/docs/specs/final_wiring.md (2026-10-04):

==================================================
SUMOX-26 COMPLETE WIRING PLAN (based on latest code: 3 opponent + 2 edge sensors)
Pack confirmed: 3x 18650 in series (3S), 9.0-12.6V range
==================================================

MATERIALS LIST + WHY EACH IS THERE
-----------------------------------
1. 3x 18650 cells (3S series)      - main power source, 9-12.6V range
2. 2x 3-way 18650 holder (1 active, 1 spare) - enables mid-match hot-swap
3. BH-042100-04U 4-way charger     - charges spare set between/before matches
4. 35A blade fuse + waterproof holder - protects pack/wiring from short-circuit fire risk
5. KCD4 main switch (DC 12-24V rated) - master on/off, cuts all power at once
6. AC rocker start/trigger switch  - low-current logic-side start trigger
7. ZORZA 5V 5A UBEC                - steps 9-12.6V pack down to safe, stable 5V
                                      (sensors are rated 4.5-5.5V, raw pack would destroy them)
8. 2200uF 35V capacitor            - bulk smoothing on positive bus, absorbs motor
                                      current spikes so UNO Q doesn't brown out
9. 470uF 16V capacitor             - local smoothing on UBEC 5V output, keeps
                                      sensor supply clean/quiet for analog readings
10. 2x BTS7960 43A motor driver    - PWM + direction control for each drive motor
11. 2x Titan 12V 200RPM motors     - drivetrain
12. 3x GP2Y0A21 IR sensor          - opponent detection (left/center/right)
13. 6x 10kOhm resistors            - 3 voltage dividers (2 per sensor) protecting
                                      UNO Q's 3.3V-max analog pins from sensor output
14. 2x TCRT5000 edge sensor        - front/back white-line detection
15. UNO Q board                    - mandated controller, runs all logic

==================================================
POWER WIRING
==================================================
Pack(+) -> 35A fuse -> KCD4 switch -> POSITIVE BUS
  reason: fuse = fire/short protection, switch = single master cutoff

POSITIVE BUS -> UNO Q VIN
  reason: powers board via its own onboard regulation

POSITIVE BUS -> BTS7960 (L) B+
POSITIVE BUS -> BTS7960 (R) B+
  reason: motors need raw pack voltage directly, not regulated 5V

POSITIVE BUS -> UBEC 5V 5A input
  reason: steps pack voltage down to safe 5V for sensors

POSITIVE BUS -> 2200uF 35V cap (+), cap(-) -> ground
  reason: dampens current spikes right at the source before they
          propagate through the whole system

UBEC 5V OUT -> 470uF 16V cap (+), cap(-) -> ground
  reason: local smoothing right where sensors draw power

UBEC 5V OUT -> all 3x GP2Y0A21 VCC
  reason: sensors need clean regulated 5V, never raw pack voltage

UBEC 5V OUT -> AC rocker start/trigger switch
  reason: low-current logic switch is fine off the regulated rail

COMMON GROUND: pack-, UNO Q GND, both BTS7960 GND, UBEC GND,
both cap negatives, all 3 GP2Y0A21 GND, both TCRT5000 GND,
all 3 divider bottom legs
  reason: one shared ground reference is mandatory -- any ground
          offset between sensor and board corrupts analog readings
          and defeats divider math

==================================================
MOTOR DRIVERS (BTS7960 x2)
==================================================
D2 -> LEFT_L_EN      D6 -> RIGHT_L_PWM (PWM)
D3 -> LEFT_R_PWM(PWM) D7 -> RIGHT_R_EN
D4 -> LEFT_R_EN       D8 -> RIGHT_L_EN
D5 -> LEFT_L_PWM(PWM) D9 -> RIGHT_R_PWM(PWM)
  reason: EN pins enable each half-bridge, PWM pins set speed/direction
Driver B+ -> positive bus, B- -> ground, M1/M2 -> motor terminals
  reason: swap M1/M2 pair (not logic pins) if a motor spins backward

==================================================
EDGE SENSORS (TCRT5000 x2: front, back)
==================================================
D10 -> EDGE_FRONT (DO)
D11 -> EDGE_BACK  (DO)
Each sensor: VCC -> 3.3V, GND -> common ground, DO -> pin above
  reason: 3.3V keeps sensor logic level matched to UNO Q's native
          digital input, no divider needed for digital signals

==================================================
OPPONENT SENSORS (GP2Y0A21 x3: left, center, right) + DIVIDERS
==================================================
A0 -> OPPONENT_LEFT   (through its own divider)
A1 -> OPPONENT_CENTER (through its own divider)
A2 -> OPPONENT_RIGHT  (through its own divider)

Each sensor: VCC -> UBEC 5V, GND -> common ground
  reason: sensor needs real 5V to operate correctly, must never
          touch raw pack voltage (9-12.6V would destroy it)

DIVIDER (build 3x, one per sensor):
Sensor Vo --- R1(10k) ---+--- UNO Q analog pin
                          |
                        R2(10k)
                          |
                      common ground
  reason: sensor output can peak near/above 3V, UNO Q ADC max is
          3.3V with thin safety margin -- divider halves the
          voltage reaching the pin, protecting the board from any
          spike, noise, or unit-to-unit variance

==================================================
NOTES
==================================================
- This plan reflects the LATEST code (3 opponent + 2 edge sensors).
  If you're still physically building toward 4+4, flag that --
  the extra sensors (A3, D12/D13) need both wiring AND code changes.
- No start/round buttons wired in current code (A4/A5 unused) --
  countdown is a fixed timer from power-on.
- Threshold constants in Hardware.h must be recalibrated using
  readings taken THROUGH the dividers, on the real UNO Q, not
  raw bench values.
==================================================

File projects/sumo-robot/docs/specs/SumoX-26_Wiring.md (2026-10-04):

# SumoX-26 — Arduino UNO Q Wiring & Pin Map (Final, v3)

This is the definitive pin assignment — safe to code your constants against right now. The power-supply *voltages* feeding some of these pins still have a few physical checks pending (listed in Section 4); those checks won't change which pin anything plugs into, only what's allowed to sit behind it before you power up.

---

## 1. Pin assignment table — this goes to that pin

| Arduino pin | Wire goes to | Signal type |
|---|---|---|
| D2 | Left BTS7960 — **L_EN** | Digital out |
| D3 | Left BTS7960 — **R_PWM** | PWM out |
| D4 | Left BTS7960 — **R_EN** | Digital out |
| D5 | Left BTS7960 — **L_PWM** | PWM out |
| D6 | Right BTS7960 — **L_PWM** | PWM out |
| D7 | Right BTS7960 — **R_EN** | Digital out |
| D8 | Right BTS7960 — **L_EN** | Digital out |
| D9 | Right BTS7960 — **R_PWM** | PWM out |
| D10 | Edge sensor 1 — **DO** | Digital in |
| D11 | Edge sensor 2 — **DO** | Digital in |
| D12 | Edge sensor 3 — **DO** | Digital in |
| D13 | Edge sensor 4 — **DO** | Digital in |
| A0 | Opponent sensor 1 — Vo (through divider) | Analog in |
| A1 | Opponent sensor 2 — Vo (through divider) | Analog in |
| A2 | Opponent sensor 3 — Vo (through divider) | Analog in |
| A3 | Opponent sensor 4 — Vo (through divider) | Analog in |
| A4 | Main Power/Arm Switch — Auxiliary contact | Digital in |
| A5 | Round-Start Toggle Switch — Match trigger | Digital in |
| D0, D1 | Free (kept clear of RX/TX) | — |
| 3.3V | → TCRT5000 VCC ×4, pending confirmation (§4) | Power out |
| 5V | Not used for external power — board is powered via VIN instead | — |
| VIN | ← battery bus (fused, switched) | Power in |
| GND | ← common ground bus | Ground |

D3/D5/D6/D9 are confirmed PWM-capable straight from Arduino's own UNO Q pinout diagram (marked with `~` on the official pin map) — same PWM set as the classic Uno, so no assumption needed there anymore.

R_IS/L_IS on both BTS7960 modules stay disconnected.

---

## 2. Signal conditioning on the way to those pins

**GP2Y0A21 → A0–A3**, each through its own divider:

```
GP2Y Vo ──── 10kΩ ────┬──── UNO Q analog pin
                      │
                     10kΩ
                      │
                     GND
```

The GP2Y0A21 is a 5V-powered analog sensor with a distance-dependent output (not a flat 0–5V swing) — the divider isn't there because the sensor "outputs 0–5V," it's there as conservative protection because the UNO Q's ADC input ceiling is 3.3V and analog-mode pins lose their 5V tolerance even where the same pin would tolerate 5V as a plain digital input. With the divider, a sensor output of X volts becomes X/2 volts at the pin — halve your math back out in code when converting ADC counts to distance.

You'll need 8× 10kΩ resistors (two per sensor) — these aren't on your current parts list yet.

**TCRT5000 → D10–D13**: direct connection, no divider — *once* the module is confirmed to run on 3.3V (see checklist).

---

## 3. Power architecture

```
3S battery pack (confirmed, measured — see §4)
    │
    ▼
35A fuse (rating to be confirmed against actual current draw — see §4)
    │
    ▼
Main rocker switch (Pin A4) — Master power/idle control
    │
    ├──→ Left BTS7960  B+  (B− → common GND)
    ├──→ Right BTS7960 B+  (B− → common GND)
    ├──→ UNO Q VIN
    └──→ UBEC input

UBEC output (5V, measured)
    ├──→ GP2Y sensors ×4 — VCC
    └──→ BTS7960 logic VCC ×2 — provisional, see §4

UNO Q 3.3V pin
    └──→ TCRT5000 ×4 — VCC — provisional, see §4

Common ground bus:
    battery− / UNO Q GND / both BTS7960 GND (logic + B−) / UBEC GND / all sensor GNDs
```

**Operational Flow**: 
1. **Main Power (A4)** is toggled ON $\rightarrow$ Robot enters Idle/Sensor-test mode.
2. **Round Switch (A5)** is toggled ON $\rightarrow$ Trigger 5-second countdown $\rightarrow$ Randomized Start $\rightarrow$ Fight.
3. **Round Switch (A5)** is toggled OFF $\rightarrow$ Match ends. Robot remains powered (A4 still ON) for immediate re-arming.

**BTS7960 logic VCC defaults to 5V, not 3.3V**, until your specific modules are confirmed otherwise. "Accepts 3.3–5V on the control inputs" and "VCC can be powered at 3.3V" are two different claims — most IBT-2/BTS7960 boards are built expecting a 5V logic supply even when their RPWM/LPWM/EN inputs happily read a 3.3V HIGH. So the control pins (D2–D9) go straight to the UNO Q's 3.3V logic as planned, but VCC gets 5V from the UBEC until a photo of your actual modules says otherwise.

Capacitors: your invoice has **one** 2200µF/35V cap, not two — so it sits across the shared motor-power distribution bus (positive/negative), close to where the two BTS7960 draw from it, rather than "one per driver." A second one would be needed if you want a local cap at each driver individually. The 470µF/16V cap goes across the UBEC's 5V/GND output.

---

## 4. Still needs a physical check before anything is powered on

| # | Item | What to check | Blocks |
|---|---|---|---|
| 1 | 3S battery pack | Measure holder output with a multimeter — expect ~9–12.6V depending on charge; confirm polarity | VIN connection |
| 2 | 18650 cells ×6 | Read the actual printed brand/model/discharge rating off the cells — "600–3800mAh" on the invoice isn't a real spec | Whether these cells are motor-suitable at all |
| 3 | 4-way charger | Confirm whether it's built to charge an assembled 3S series pack, or individual cells only | Charging procedure |
| 4 | 35A fuse | Confirm the rating actually fits your measured motor stall current + wiring/connector ratings, don't assume "fuse present = safe" | Fuse sizing |
| 5 | BTS7960 modules ×2 | Photo front + back, read the printed VCC/input spec off the board | Whether VCC stays at 5V default or moves to 3.3V |
| 6 | TCRT5000 modules ×4 | Read the printed voltage spec; confirm DO is actively driven and rises to VCC | Whether 3.3V is used or an alternative is needed |
| 7 | GP2Y sensors ×4 | Confirm actual printed part number (your invoice says SK0F; commonly documented part is YK0F) | Confirms exact output range |
| 8 | Rocker switch | Multimeter-test the 3 pins to identify common / switched-output / LED-negative before wiring | Main power wiring |
| 9 | 10kΩ resistors | Not yet on your parts list — need 8 for the GP2Y dividers | GP2Y wiring |

None of these change the pin table in Section 1 — they only decide what's allowed to sit on the power rails behind it. You can write and test all the digital/PWM/edge-sensor code against Section 1 right now; hold off connecting the battery until the checklist above is cleared.

---

## 5. Wiring practice notes

- Motor power path (battery → fuse → switch → driver B+/B−, driver → motor) needs real gauge wire, not the jumper-wire kit — jumpers are for logic/sensor signals only.
- Electrolytic capacitors are polarized: + to positive rail, − to ground, never reversed.
- Two UBECs (if you use both) are separate regulated branches, not isolated ones — they still share a common ground with everything else. Don't rely on a second UBEC alone for noise immunity; short sensor wiring and physical separation from motor-current paths do more of that work.
- One common ground, always, across every rail above.

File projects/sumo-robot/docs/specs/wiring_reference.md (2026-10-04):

==================================================
SUMOX-26 WIRING REFERENCE (current hardware.h)
==================================================

--- POWER ---
6x 18650 pack -> 35A fuse -> KCD4 main switch -> positive bus
Positive bus -> UNO Q VIN
Positive bus -> BTS7960 (L) B+
Positive bus -> BTS7960 (R) B+
Positive bus -> ZORZA 5V 5A UBEC input
Positive bus -> 2200uF 35V cap (+), cap (-) -> common ground
UBEC 5V out -> 470uF 16V cap (+), cap (-) -> common ground
UBEC 5V out -> GP2Y0A21 VCC (all sensors)
COMMON GROUND: pack-, UNO Q GND, both BTS7960 GND, UBEC GND,
both cap negatives, all GP2Y0A21 GND, all TCRT5000 GND,
all divider bottom legs -- ONE shared ground net, no exceptions

--- MOTOR DRIVERS (BTS7960 x2) ---
D2 -> LEFT_L_EN
D3 -> LEFT_R_PWM (PWM)
D4 -> LEFT_R_EN
D5 -> LEFT_L_PWM (PWM)
D6 -> RIGHT_L_PWM (PWM)
D7 -> RIGHT_R_EN
D8 -> RIGHT_L_EN
D9 -> RIGHT_R_PWM (PWM)
Both drivers: B+ -> positive bus, B- -> common ground
M1/M2 -> motor terminals (swap pair to fix spin direction, never rewire logic pins)

--- EDGE SENSORS (TCRT5000 x2 -- FRONT/BACK ONLY, matches this code) ---
D10 -> EDGE_FRONT (DO)
D11 -> EDGE_BACK (DO)
Each sensor: VCC -> 3.3V, GND -> common ground, DO -> pin above

--- OPPONENT SENSORS (GP2Y0A21 x3 -- LEFT/CENTER/RIGHT) ---
A0 -> OPPONENT_LEFT (through its own divider)
A1 -> OPPONENT_CENTER (through its own divider)
A2 -> OPPONENT_RIGHT (through its own divider)
Each sensor: VCC -> UBEC 5V (NOT UNO Q 3.3V/5V pin), GND -> common ground

--- VOLTAGE DIVIDER (build 3x, one per sensor, 6 resistors total) ---
GP2Y0A21 OUT --- R1 (10k) ---+--- UNO Q analog pin (A0/A1/A2)
|
R2 (10k)
|
common ground

Steps per sensor:

1. R1 leg 1 -> sensor OUT wire
2. R1 leg 2 -> tap point -> UNO Q analog pin (this is what gets read)
3. Same tap point -> R2 leg 1
4. R2 leg 2 -> common ground
   Result: pin reads ~half of sensor output (5V sensor swing -> ~2.5V at pin, safe under 3.3V max)

--- NOT WIRED IN THIS CODE VERSION ---

- No A3 (4th opponent sensor) -- add if you physically have 4 sensors
- No D12/D13 (3rd/4th edge sensor) -- add if you physically have 4 sensors
- No A4/A5 start/round buttons -- currently just a fixed 5s countdown from power-on

==================================================

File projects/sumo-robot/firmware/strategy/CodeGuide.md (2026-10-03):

# SumoX-26 code guide (v2.4)

## 1. The idea in one paragraph
Every **5 ms** the robot repeats one cycle (`robotLoop()` in `Robot.cpp`): **check the stop switch → read sensors → check the edge (top priority) → ask the strategy what to do → drive the motors → update the map.** The strategy is a small state machine: sweep, search, align, charge, return, back off. A dead-reckoning map estimates where we are and how wrong that guess could be, and it limits our speed so we can stop before the rim.

## 2. Files
| File | Job (in plain words) |
|---|---|
| `SumoX26.ino` / `v2.4_Strategy.ino` | Entry point. `setup()` calls `initRobot()` once, `loop()` calls `robotLoop()` forever. |
| `Hardware.h` | Numbers **you type**: pins, rulebook values, ruler/stopwatch measurements, tuning knobs. |
| `Formulas.h` | Numbers the code **calculates** from `Hardware.h`. Never type here. (`Hardware.h` includes it at the bottom.) |
| `Motors.cpp/.h` | The only code that touches motor pins. |
| `Sensors.cpp/.h` | Decides what counts as "opponent" and "edge". |
| `Map.cpp/.h` | Position guess, uncertainty, speed limit. |
| `Strategy.cpp/.h` | The brain: picks what to do. |
| `Robot.cpp/.h` | The conductor: startup, stop switch, priority order, edge recovery. |
| `Calibrate.ino` (separate folder) | Prints sensor readings so you can fill in thresholds. |

## 3. Hardware.h — what you type
- **Wiring:** `LEFT_L_EN`, `LEFT_R_PWM`, `LEFT_R_EN`, `LEFT_L_PWM` (pins 2-5) and the right driver (6-9); `EDGE_FRONT` D10, `EDGE_BACK` D11; `OPPONENT_LEFT/CENTER/RIGHT` A0-A2; `START_BUTTON_PIN` A4 (the rocker).
- **Flags:** `LEFT_MOTOR_INVERTED` / `RIGHT_MOTOR_INVERTED` (flip if a wheel spins backward), `EDGE_WHITE_STATE` (fallback only, auto-detected at start), `POWER_BUTTON_PRESENT = false` (KCD4 is the power switch), `START_IS_LATCHING = true` (rocker stays ON), `START_SWITCH_ANALOG = true` (A4 is read as a voltage), `REARM_ENABLED`.
- **Rulebook:** `ARENA_TOTAL_DIAMETER_CM` 150, `ARENA_FRAME_THICKNESS_CM` 3, start-line numbers, `START_DELAY_MS` 5000, `STALEMATE_HARD_CEILING_MS` 30000.
- **Robot measurements:** `ROBOT_LENGTH_CM`, `REAR_TO_AXLE_CM`, `WEDGE_TO_FRONT_SENSOR_CM` 4.7, `REAR_TO_BACK_SENSOR_CM` 3.6, `ROBOT_WIDTH_CM`.
- **Motion (placeholders until measured):** `DRIVE_SPEED_MAX_CMS`, `SPIN_RATE_CW_DEGS`, `SPIN_RATE_CCW_DEGS`, `STOP_DISTANCE_CM`, `FRICTION_MU`, `MIN_MOVE_PWM`.
- **Sensor calibration:** `SENSOR_DIVIDER_RATIO` (9.9k/9.9k = 0.5), old bench numbers (`BENCH_*`), five `MEASURED_*` values, the switch `USE_MEASURED_THRESHOLDS`, and `ADC_NOISE_SIGMA`.
- **Tuning knobs:** `ALIGN_*`, `STALEMATE_*`, `EDGE_RECOVER_*`, `COMMIT_VOID_PWM`, etc.

## 4. Formulas.h — what the code calculates
- **Arena:** `ARENA_RADIUS_CM` 72 (black surface), `ARENA_OUT_RADIUS_CM` 75 (out line).
- **Robot shape:** `ROBOT_L_F_CM` (pivot to nose), `ROBOT_L_B_CM` (pivot to rear), `EDGE_SENSOR_FRONT/BACK_OFFSET_CM`, `ROBOT_R_SWING_CM` (farthest corner when spinning), `START_POSE_RADIUS_CM`.
- **Opening sweep:** `OPEN_SWEEP_HALF_ANGLE_DEG` = atan(20 / (22 + nose length)) + aiming error. `OPEN_SWEEP_LEG_A_MS`/`LEG_B_MS` turn it into times.
- **Motion:** `DRIVE_DECEL_CMS2` = v² / 2d. `COMMIT_SOFT_START_S` = v / (μg), the fastest push-off without wheel slip. `MOTOR_SLEW_PWM_PER_MS` = how fast power may rise.
- **Thresholds:** `WEAK_THRESHOLD`, `STRONG_THRESHOLD`, `NEAR_THRESHOLD`, `CONTACT_BAND_LOW/HIGH`, `PEAK_BAND_LOW/HIGH`. With `USE_MEASURED_THRESHOLDS = false` they are the old bench numbers x 0.5. Two `static_assert` lines stop the build if their order is wrong.
- **Timing:** `SENSOR_SAMPLE_INTERVAL_MS` 15 (from the sensor's refresh time), `WEAK_CONFIRM_SAMPLES` 4, `LOST_CONTACT_GRACE_MS` 60.
- **Noise filter:** `ADC_OVERSAMPLE_N` = number of reads we take and take the median of. N = (noise / (smallest threshold gap / 6))², made odd.
- **Start/stop:** `START_COUNTDOWN_MS` 5050, `REARM_HOLD_MS` 300, `START_SWITCH_THRESHOLD_ADC` ~387.
- **Search/align:** `SEARCH_SPIN_PWM`, `ALIGN_TIMEOUT_MS`, `SEARCH_COVERAGE_SWEEP_DEG` 270, `SEARCH_DWELL_MS` 60.
- **Stalemate:** `STALEMATE_BACKOFF_CM` = how far the 300 ms back-off travels.

## 5. Motors.cpp
- `initMotors()` enables the drivers at PWM 0. `disableMotorDrivers()` turns them fully off (boot state). `stopMotors()` stops instantly.
- `drive(left, right, immediate)`: clamps to ±255, limits acceleration (`slewToward()`), applies the inversion flags, and writes PWM through `setSide()` (positive → R pin, negative → L pin). Slowing down is never delayed. A reversal goes through zero first. `immediate = true` skips the limiter (edge recovery, stopping).
- `curL`/`curR` remember what was sent; `getAppliedLeft()`/`getAppliedRight()` give it to the map.

## 6. Sensors.cpp
- `readFiltered(pin)`: one throwaway read, then N reads, median. The UBEC ripple spikes get thrown out.
- `updateOpponentSensors()`: every 15 ms updates three channels (`updateChannel()`):
  - **Detected** = 2 strong readings (≥125) in a row, or 4 weak (≥75) in a row.
  - **Cleared** = 2 misses in a row.
  - **`near` latch** = set once a detected target reads ≥237, cleared when it's lost.
- `anyContact()`: true if `near` was latched **and** the reading is now in the contact band. The sensor peaks at ~6-10 cm then drops, so "peaked, then dropped" means touching.
- `primeOpponentSensors()` wipes the state. `getOpponentReadings()` gives raw numbers; `getOpponentDetection()` gives yes/no flags.
- **Edge:** `calibrateEdgePolarity()` reads both edge sensors while the robot sits on black and learns which pin state means white (falls back to `EDGE_WHITE_STATE` if they disagree). `readEdgeSensors()` reads twice, 200 µs apart, and both must agree.

## 7. Map.cpp
- **Pose** = x, y (cm from arena center) and heading. `initMap()` starts at (−`START_POSE_RADIUS_CM`, 0) facing the center.
- `mapUpdateMotion()`: moves the pose from the PWM actually applied (dead reckoning — it drifts).
- `mapUpdateContact()`: during a push the wheels slip, so x, y freeze and uncertainty grows 45 cm/s.
- **U** (`getUncertainty()`) grows with distance, turning, heading error and pushing.
- `mapSnapEdge()`: an edge hit tells us exactly where we are (radius 72). Position corrects and U resets; heading error does not.
- `isMapVoid()`: true once U ≥ 72 − swing radius − stop distance (36.8 cm by default). Past that the map isn't trusted.
- `getGovernedMaxSpeedCms()`: top speed that still lets us stop before the rim = √(2 × decel × margin).
- `shouldReturn()`, `getReturnHeadingDeg()`, `getReturnTurnDeltaDeg()`: "are we off-center, and which way to face the center".
- `getRearMaxRadius()`: how far the rear corners reach (used before backing off).
- `isPhantomDetection()` and `isEdgeReadingImplausible()` exist but are switched off.

## 8. Strategy.cpp — the states
Variables to know: `state`, `lastSeenSign` (+1 left, −1 right, 0 never), `alignFlipCount`, `contactStartMs`, `lastDetectMs`, `returnPhase`, `stalemateBreakCount`.
1. **OPEN_SWEEP:** spin left 35.5° (295 ms), then right 71° (590 ms). Any sighting ends it early.
2. **SEARCH:** spin up to 270° toward the last-seen side, pause 60 ms, flip direction. After the first leg: `RETURN` if the map is trusted and we're off-center, otherwise keep scanning.
3. **ALIGN:** spin toward the side that sees the opponent (170 PWM plus up to 85 more as the reading rises). Center sees it → charge. Lost → search. 3 side flips or 562 ms → charge anyway.
4. **COMMIT (charge):**
   - Touching: 255 PWM plus steering trim.
   - Not touching: ramp up over 76 ms, capped by the governor (never below `MIN_MOVE_PWM`, or `COMMIT_VOID_PWM` if the map is void).
   - Target lost for 60 ms → search.
   - Pushing for 9 s → `STALEMATE_BREAK`, **but only if** `rearClearForBackoff()` says the rear is provably clear. During a push the map usually becomes void, so most of the time it just keeps pushing.
5. **STALEMATE_BREAK:** reverse 300 ms (about 9 cm) with a sideways bias that alternates each time, then re-pick from the sensors.
6. **RETURN:** turn to face the center (within 5°), drive there until the distance ≤ U, then search. If it sees an opponent it aborts and fights (a center sighting always; a side sighting only if our swing radius won't hang over the edge).

## 9. Robot.cpp — the conductor
**Start (`initRobot()` then `armAndStart()`):**
1. Drivers off. `constantsValid()` halts the robot if a key constant is zero or NaN.
2. `initMotors()`, `initSensors()` (10-bit ADC).
3. `armAndStart()`: `initMap()`, `primeOpponentSensors()`, `waitForPress()` (rocker released 30 ms, then ON 30 ms — a rocker already ON at power-up is ignored until you flip it OFF and ON), `calibrateEdgePolarity()`, a **5.05 s countdown with motors at 0** (sensors still reading), then `resetStrategy()`: attack if an opponent is visible, otherwise start the sweep.

**Every tick (`robotLoop()`):**
1. Stop check: rocker OFF for 300 ms (`REARM_HOLD_MS`) → `armAndStart()` again (motors stop, wait for the next ON).
2. `updateOpponentSensors()`, `readEdgeSensors()`.
3. **Both** edge sensors white → drive up to 150 ms toward the end nearer the center (backward if the map is void).
4. **One** edge sensor white → `mapSnapEdge()` then recover (`handleEdgeRecoveryTick()`): front fired → reverse, back fired → forward, at 170 PWM (255 if touching the opponent). It ends when the opposite sensor fires, or the sensor has been clear for 110 ms and our swing fits inside the ring, or after 700 ms. Then it re-engages if an opponent is visible, otherwise returns/searches.
5. Otherwise: `updateStrategy()` picks the motor command, `drive()` applies it, and the map updates (`mapUpdateContact()` if touching, else `mapUpdateMotion()`).

**Priority:** stop switch → edge → strategy.

## 10. Calibrate.ino
Prints for A0, A1, A2 and A4: `mean`, `sigma` (noise), `min`, `max`, `us/read`, plus the two edge pin states. Run with motors off, then on (`RUN_MOTORS`). Use the numbers to fill the `MEASURED_*` values and `ADC_NOISE_SIGMA` in `Hardware.h`.

## 11. One round, as a story
Robot is placed, the lid is lifted, the whistle blows, you flip the rocker. It learns edge polarity, stays still 5.05 s, then attacks if it sees the opponent or sweeps left and right until it does. It charges; if the opponent disappears it searches; if an edge sensor sees white it backs away first and thinks later. After the round you flip the rocker OFF and the robot stops and waits for the next ON.

## 12. Honest limits (say these first)
- Speed, spin rate, friction and stop distance are placeholders until measured.
- Sensor thresholds are scaled estimates until measured through the dividers.
- The left/right turn direction must be checked on the real robot.
- The front edge sensor is 4.7 cm behind the wedge tip but the white frame is only 3 cm, so the tip can be past the line when the sensor fires. The map's speed limit helps; it cannot be guaranteed.
- When reversing onto the edge, the wheels are already over the white when the back sensor fires.
- The phantom gate is off, so a person standing near the arena (the safety zone) could be seen as an opponent.
- Logic was tested in a PC simulation (scripted sensors, 5 random-input runs of 90 simulated seconds, no errors). Physics was not tested.

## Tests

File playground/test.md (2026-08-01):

# Markdown Playground

This file exists to test Markdown syntax and rendering.

---

## Headings

### Heading 2

#### Heading 3

##### Heading 4

---

## Text Formatting

Normal text.

This is **bold text**.

This is *italic text*.

This is ***bold and italic text***.

This text is ~~strikethrough~~.

---

## Lists

### Unordered List

- Python
- Git
- GitHub
- Data Analysis
  - NumPy
  - Pandas
  - Matplotlib

### Ordered List

1. Learn Python
2. Learn Data Analysis
3. Build Projects
4. Document Everything

---

### Links

GitHub:
[https://github.com](https://github.com)

Markdown guide:
[Markdown Guide](https://www.markdownguide.org)

---

## Images

Example:

Python Logo

---

## Code

Inline code:

Use `git status` to check repository state.

Code block:

```python
def hello():
    print("Hello Markdown")
    
hello()
```

Bash:

```bash
git add .
git commit -m "message"
git push
```

---

### Tables

| Tool | Purpose | Status |
| --- | --- | --- |
| Python | Programming | Completed |
| Git | Version Control | Completed |
| NumPy | Numerical Computing | Learning |
| Pandas | Data Analysis | Future |

---

## Quotes

> Learning by building is better than memorizing.

---

## Checkboxes

- [x] Learn Git basics
- [x] Create GitHub repository
- [ ] Master NumPy
- [ ] Build trading projects

---

## Horizontal Line

---

## Escaping Characters

Sometimes Markdown symbols need escaping:

\*not italic\*

\# not a heading

---

## HTML Inside Markdown

This text is centered using HTML.`

---

## Math

Inline:

$E = mc^2$

Block:

$$
\sum_{i=1}^{n} i = \frac{n(n+1)}{2}
$$

---

## Final Notes

Markdown is:

- simple
- readable
- supported by GitHub
- useful for documentation

This file is only a playground for testing syntax.

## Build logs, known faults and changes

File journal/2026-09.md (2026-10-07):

# Journal 2026-09

Format: `YYYY-MM-DD | learn/build/plan/research/achieve | what | files`. Newest at the bottom. Entries below are from file dates; earlier history can be backfilled from `git log --reverse --date=short --pretty="%ad | %s"`.

2026-09-24 | build | scanned handwritten sumo design/calibration notes | projects/sumo-robot/notes/scans/2026-09-24-scan.pdf
2026-09-25 | build | scanned notes and design photos for body v2; first GP2Y0A21 calibration sketches | projects/sumo-robot/notes/scans/2026-09-25-scan.pdf, projects/sumo-robot/design/cad-v2/
2026-09-26 | build | parametric CAD scripts for the front wedge and main deck | projects/sumo-robot/design/parametric/
2026-09-30 | build | scanned notes | projects/sumo-robot/notes/scans/2026-09-30-scan.pdf

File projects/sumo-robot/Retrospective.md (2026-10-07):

# Sumo-Robot Retrospective (SumoX-26)

Outcome: eliminated after 3 matches (1 skipped, 2 stalemates). Code on the board: v2.4, untested on the robot. Two causes: wiring never finished; robot too low for opponent sensors to see. Source: 33 chat summaries (2 accounts), see `LOG.md`.
This was the first project run through the AI-context setup (`AI-CONTEXT.md`, STATE/LOG per project), so the lessons below are also the first draft of a reusable project template.

## Stage 1: primary research (own measurements, rulebook, hardware facts)
Worked
- TCRT5000 height sweep found the only usable band (1.5-3 cm, white HIGH / black LOW).
- GP2Y0A21 bench bands (<100 none, 250-350 at 0-10 cm, 600-700 at 10 cm) exposed the near-field dip, which changed the design (detect-level latch instead of engage-level).
- Rulebook cross-checks turned up the rules that drive code: 5 s stationary, 30 s stuck rule, 25-30 cm safety zone, no changes after inspection, front not white.
- STL parse showed 200.006 mm (zero margin) before inspection.
Did not work
- Calibration started late and was partial: first GP2Y logs were unusable (flat 330-360 with dropouts, likely loose wiring); TCRT5000 units varied 0.5-4 cm in range, one possibly damaged, no trim pot.
- Thresholds were measured without dividers, then scaled x0.5 (derived, never measured through the dividers).
- Brown start lines never tested on the real arena (later sidestepped with a box lid).
- Motion constants (speed, spin rate, stop distance, mu, min PWM) never measured; T0-T5 sketches were written but not run on the robot.
- No weigh-in, battery/motor weights estimated; arena size stated as 100 cm in one sketch vs 150 cm in the rulebook.
- Ground clearance never compared with opponent sensor height: the robot was undetectable.
Template rule: list every constant the strategy needs, measure each on the real hardware before writing strategy code, and mark the rest `PLACEHOLDER`.

## Stage 2: secondary research (repos, papers, forums, other AIs)
Worked
- Repos gave usable patterns (rolling average, stuck counter, test-sketch-per-subsystem order); architecture consensus: Search / Attack / Edge-avoid, edge check first.
- A thesis comparison (tornado search worst, tracking best) backed the bounded-sweep + align design.
- UNO Q docs caught real wiring risks: A0/A1 not 5 V tolerant, divider needed on GP2Y outputs.
- Forum finding: `pinMode(OUTPUT)` on a PWM pin breaks `analogWrite` on UNO Q.
Did not work
- Several "research" claims were recalled, not looked up (GP2Y fold-back distance, datasheet voltages, TCRT5000 polarity).
- An AI research report cited Uno R3 docs for UNO Q; a boot time of ~43 s stayed unconfirmed; a quoted "IR-absorbing brown" rule clause was not in the SumoX-26 rulebook.
- Reviewers contradicted each other (reposition direction inverted twice, pivot sign rules, spin polarity), costing several chats.
- Some repos blocked by robots rules; one licence conflict (CC BY-NC-SA vs GPL-3.0), so ideas only.
Template rule: tag each research line SOURCED or RECALLED; verify RECALLED items on the target hardware before they become constants. Treat a second AI's review as a claim to verify, not a patch to apply.

## Stage 3: implementation (code, build, test)
Worked
- Layered files (Hardware / Motors / Sensors / Robot / Strategy) and version folders; later Hardware.h + Formulas.h so every number is traceable.
- Host-side stubs, scenario tests, PC sim and fuzz runs caught real bugs: switch blip freezing the robot for 5.2 s, inverted spin polarity (ALIGN turned away, RETURN deadlock), stale buffers, dead start switch after match 1.
- `static_assert`s on thresholds; software-only mitigation for UBEC ripple (median oversampling, release hysteresis).
- Logic kept on the MCU; fallbacks kept (v4, BlindSumo).
Did not work
- Strategy rewritten four times (Hybrid, Ram, map-based, Blind); each rewrite reset calibration and moved effort away from wiring.
- Piecemeal patches confused the user; in roughly ten chats a patch was "given, application unconfirmed". Full-file replacements worked better.
- Spec docs drifted from the code (twice flagged).
- Not compiled on the real UNO Q core in the summaries; last-day IDE errors (`analogWriteResolution`, `arduino:zephyr` platform).
- A redesigned printable chassis was rejected; the final robot was too low for opponent detection.
- Wiring was left to the competition day and never finished.
Template rule: freeze the hardware build date first; no new strategy rewrite after the freeze; confirm each patch is applied (diff against the repo) before the next review.

## Decision register (final choices; superseded ones in brackets)
| Decision | Reason | Superseded / rejected |
|---|---|---|
| Edge check first, every loop | self-exit is a guaranteed loss | attack-before-edge (one repo) |
| Layered multi-file sketch, one folder, one .ino | Arduino compiles the folder | single merged .ino |
| Wiring v3 pin map D2-D13 / A0-A3, start on A4 | most reviewed, stable | 2 other pin maps |
| GP2Y on 5 V with 10k/10k divider; TCRT5000 on 3.3 V | A0/A1 not 5 V tolerant | direct connection |
| Median filter, not mean | spikes | mean [10-bit/12-bit ADC flip-flopped] |
| Detect-level (not engage-level) latch for contact | contact reads 250-350 < engage 465 | engage threshold |
| One strategy (Hybrid) over 3 selectable | no mode switch needed | S1/S2/S3 toggle |
| v5 center-anchored map, ram at t=5 s | known arena geometry | tornado search, 41-block grid |
| Latching rocker on A4 via 3.3 V + pull-down | 5 V must not reach the pin | push button, 1.2 s hold-to-stop |
| Hardware.h / Formulas.h split, thresholds x0.5 | traceable numbers; dividers halve ADC | single file |
| Keep v4 as fallback | safety | none |
| BlindSumo as last-resort fallback | sensors unreliable | not used at the event |

## Open at the end (never resolved)
- Brown-line behaviour of TCRT5000 on the real arena; edge polarity (auto-detect added, not verified).
- GP2Y thresholds through the dividers; SENSOR_PEAK 220 flagged as possibly ~2x low.
- All motion constants; motor direction and corner pin mapping; BTS7960 VCC and 3.3 V logic check.
- KCD4 DC rating; battery type; detachable wedge vs rule 4.7 (ask referee).
- Compile and run on the real UNO Q core; `STALEMATE_BREAK_ENABLED=false` edit not confirmed applied.

## Project template (draft, from this project)
1. Primary research: rulebook checklist; constants register (name, how to measure, status); bench sketches per sensor and for motion; weigh-in; opponent-view check (ground clearance, sensor heights).
2. Secondary research: sources tagged SOURCED / RECALLED; repo/licence notes; second-AI reviews logged as claims with a verification step.
3. Implementation: hardware freeze date; wiring tested end-to-end before strategy work; one version per day with a fallback; compile on the real target early; patches as full files or diffs checked against the repo; end-of-session LOG line and STATE update.

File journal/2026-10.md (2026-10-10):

# Journal 2026-10

Format: `YYYY-MM-DD | learn/build/plan/research/achieve | what | files`. Newest at the bottom.

2026-10-04 | achieve | competed in SumoX-26 (Dubai TechBots League); eliminated after 3 matches | projects/sumo-robot/STATE.md, certificates/robotics/sumox-2026-competition.pdf
2026-10-04 | build | set up MCP-based logging for the repo (AI-CONTEXT, STATE, LOG per project) | AI-CONTEXT.md
2026-10-06 | build | backfilled the Sumo-Robot LOG from 33 chat summaries; wrote STATE constants with calculations and the retrospective | projects/sumo-robot/LOG.md, STATE.md, Retrospective.md
2026-10-06 | build | restructured the repo (learning/, projects/, certificates/, journal/, _local/); rewrote README, AI-CONTEXT and indexes | README.md, AI-CONTEXT.md, learning/README.md
2026-10-08 | build | pushed the restructure to GitHub as 12 commits; removed personal lines from a public commit | README.md, projects/sumo-robot/notes/chat-summaries/
2026-10-08 | plan | wrote the reusable project workflow (stages, session loop, git routine, prompts) | projects/WORKFLOW.md
2026-10-08 | research | validated the AMD AI Academy Challenge and set up its project folder | projects/amd-hackathon/STATE.md, projects/amd-hackathon/docs/brief.md, projects/README.md
2026-10-08 | research | first AMD link was the wrong event; set up AMD Developer Hackathon ACT III (teams of 1-6, build 10-12 to 10-18) as its own project; wrote brief digest, added index row | projects/amd-hackathon-act-iii/STATE.md, projects/amd-hackathon-act-iii/docs/brief.md, projects/README.md
2026-10-08 | plan | completed ACT III initial setup: complete brief incl. rule book and submission rules, STATE rules/constants, research queues listed (not started) | projects/amd-hackathon-act-iii/STATE.md, projects/amd-hackathon-act-iii/docs/brief.md
2026-10-09 | research | ACT III primary research checklist written: 12 findings (track-count conflict, AMD as prize gate, Evolus credit and log checks), 12 unknowns with sources, 9 constants to measure; STATE and LOG updated | projects/amd-hackathon-act-iii/docs/primary-research.md, projects/amd-hackathon-act-iii/STATE.md, projects/amd-hackathon-act-iii/LOG.md
2026-10-09 | decision | ACT III: team formed, initial idea is an AI-generated 3D indoor walkthrough from static images (hotels, factory training), roles and PR workflow set; track open | projects/amd-hackathon-act-iii/STATE.md, projects/amd-hackathon-act-iii/LOG.md

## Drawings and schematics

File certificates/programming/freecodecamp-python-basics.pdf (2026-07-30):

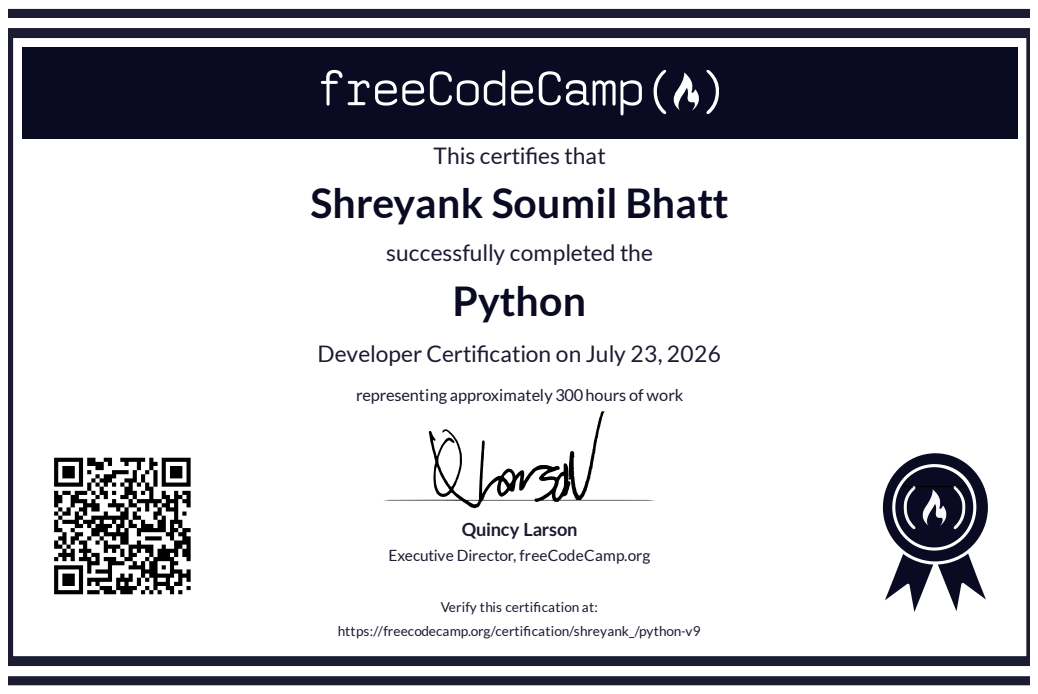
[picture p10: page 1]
Quincy Larson

This certifies that
Shreyank Soumil Bhatt

successfully completed the
Python

Developer Certification on July 23, 2026

representing approximately 300hours of work

Executive Director, freeCodeCamp.org

Verify this certification at:

https://freecodecamp.org/certification/shreyank_/python-v9

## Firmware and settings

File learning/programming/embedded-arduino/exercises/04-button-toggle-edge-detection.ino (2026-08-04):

/*
  Exercise 04 - Button Toggle LED (Edge Detection)

  Purpose:
  - Pressing the button toggles the LED ON/OFF.
  - The LED keeps its state after the button is released
    (unlike Exercise 02, where the LED only stayed on while HELD).

  Hardware:
  - Built-in LED on Arduino UNO -> Pin 13
  - Push button -> Pin 2 and GND

  INPUT_PULLUP logic:
  - Button released -> HIGH
  - Button pressed  -> LOW

  This works because the Arduino internally pulls the pin HIGH.
  When the button is pressed, it connects the pin to GND, causing LOW.

  This is a step up from Exercise 02: instead of just checking the
  CURRENT button state every loop, this compares the current reading
  to the PREVIOUS reading to detect the exact moment the button goes
  from released to pressed (a "falling edge": HIGH -> LOW). See notes
  file for why this matters.
*/

// Stores the current LED state
// false = OFF
// true  = ON
bool ledState = false;

// Stores the previous button reading
// Used to detect when the button changes from HIGH -> LOW
bool previousButtonState = HIGH;

// Pin definitions
const int LED = 13;
const int BUTTON = 2;

void setup() {
  // Configure LED pin as an output
  pinMode(LED, OUTPUT);

  // Configure button pin as an input using internal pull-up resistor
  pinMode(BUTTON, INPUT_PULLUP);

  // Start serial communication for debugging
  Serial.begin(9600);
}

void loop() {

  // Read the current state of the button
  // Returns:
  // HIGH -> button released
  // LOW  -> button pressed
  bool buttonState = digitalRead(BUTTON);

  /*
    Detect a button press.

    We are looking for the transition:

    HIGH -> LOW

    Meaning:
    Previous loop: button was released
    Current loop: button is now pressed

    This prevents the LED from toggling repeatedly
    while the button is being held down.
  */
  if (previousButtonState == HIGH && buttonState == LOW) {

    // Toggle LED state:
    // false becomes true
    // true becomes false
    ledState = !ledState;

    // Apply the new LED state
    digitalWrite(LED, ledState);

    Serial.println("Button Pressed");
  }

  // Save current button state for the next loop
  previousButtonState = buttonState;

  // Small delay to prevent accidental multiple readings
  delay(50);
}

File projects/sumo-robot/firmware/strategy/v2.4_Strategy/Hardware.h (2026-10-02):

#ifndef HARDWARE_H
#define HARDWARE_H
#include <Arduino.h>
#include <math.h>

// HARDWARE.H = everything YOU type: wiring, rulebook numbers, ruler/stopwatch measurements, tuning knobs.
// FORMULAS.H = everything CALCULATED from these (included at the bottom; only edit if the maths changes).

// ================= WIRING (matches SUMOX-26 wiring plan) =================
const int LEFT_L_EN = 2, LEFT_R_PWM = 3, LEFT_R_EN = 4, LEFT_L_PWM = 5;
const int RIGHT_L_PWM = 6, RIGHT_R_EN = 7, RIGHT_L_EN = 8, RIGHT_R_PWM = 9;
const int EDGE_FRONT = 10, EDGE_BACK = 11;
const int OPPONENT_LEFT = A0, OPPONENT_CENTER = A1, OPPONENT_RIGHT = A2;
const int POWER_BUTTON_PIN = A3, START_BUTTON_PIN = A4;

const bool LEFT_MOTOR_INVERTED = false;  // flip if that wheel spins backward (OR swap M1/M2, never both)
const bool RIGHT_MOTOR_INVERTED = true;
const int EDGE_WHITE_STATE = HIGH;       // FALLBACK only: Sensors.cpp auto-detects polarity at start from the black surface under the robot

const bool POWER_BUTTON_PRESENT = false; // KCD4 cuts battery power, nothing on A3
const bool START_IS_LATCHING = true;     // A4 is a rocker: ON = run, OFF = stop
const bool START_SWITCH_ANALOG = true;   // read A4 as a voltage (3.3V or divided 5V feed)
const bool BUTTON_ACTIVE_LOW = false;
const bool REARM_ENABLED = true;
const unsigned long BUTTON_DEBOUNCE_MS = 30;
const int SENSOR_ADC_BITS = 10;          // VERIFY: NoiseLog max reading tops out near 1023

// ================= RULEBOOK =================
const float ARENA_TOTAL_DIAMETER_CM = 150.0f;    // §5.1
const float ARENA_FRAME_THICKNESS_CM = 3.0f;     // §5.1 white frame
const float START_LINE_CENTER_RADIUS_CM = 10.0f; // §5.2
const float START_LINE_THICKNESS_CM = 2.0f;      // §5.2
const float START_LINE_LENGTH_CM = 20.0f;        // §5.2 max
const float SAFETY_ZONE_MIN_CM = 25.0f;          // §9.3
const unsigned long START_DELAY_MS = 5000UL;     // mandatory stationary delay
const unsigned long START_DELAY_MARGIN_MS = 50;  // errs on the late side only
const unsigned long STALEMATE_HARD_CEILING_MS = 30000UL; // rule 6.6.D

// ================= ROBOT MEASUREMENTS (ruler, wedge ON) =================
const float ROBOT_LENGTH_CM = 20.0f;         // MEASURE: wedge tip to chassis rear
const float REAR_TO_AXLE_CM = 3.6f;          // MEASURE: chassis rear to wheel axle line
const float WEDGE_TO_FRONT_SENSOR_CM = 4.7f; // measured
const float REAR_TO_BACK_SENSOR_CM = 3.6f;   // measured
const float ROBOT_WIDTH_CM = 20.0f;          // MEASURE
const float ROBOT_TRACK_CM = 15.0f;          // MEASURE: spacing of the two driven wheels

// ================= MOTION (placeholders until measured) =================
const float DRIVE_SPEED_MAX_CMS = 45.0f;  // MEASURE: distance / time at PWM 255
const float SPIN_RATE_CW_DEGS = 120.0f;   // MEASURE
const float SPIN_RATE_CCW_DEGS = 120.0f;  // MEASURE
const float SPIN_DRIFT_PER_REV_CM = 5.0f; // MEASURE
const float STOP_DISTANCE_CM = 16.0f;     // MEASURE: slide after cutting power at full speed
const float FRICTION_MU = 0.6f;           // MEASURE: spring-scale pull / weight
const float THETA0_UNCERTAINTY_DEG = 8.0f;
const float U0_POSITION_CM = 5.0f;
const float HEADING_DRIFT_PER_REV_DEG = 3.0f;
const float K_ERR_PATH_FACTOR = 0.15f;
const int MIN_MOVE_PWM = 90;              // MEASURE: lowest PWM that moves the loaded robot

// ================= OPPONENT SENSOR CALIBRATION =================
// Old bench readings were taken WITHOUT the dividers. Through 9.9k/9.9k every reading is halved,
// so safe defaults = old numbers x ratio. Once measured through the dividers: type the 5 MEASURED_ values, set USE_MEASURED_THRESHOLDS = true.
const float SENSOR_DIVIDER_RATIO = 9.9f / (9.9f + 9.9f); // multimeter: both resistors read 9.9k
const int BENCH_NO_OBJECT_MAX = 100;
const int BENCH_CONTACT_LOW = 250, BENCH_CONTACT_HIGH = 350;
const int BENCH_PEAK_LOW = 600, BENCH_PEAK_HIGH = 700;
const bool USE_MEASURED_THRESHOLDS = false;
const int MEASURED_WEAK = 75;
const int MEASURED_CONTACT_LOW = 125, MEASURED_CONTACT_HIGH = 175;
const int MEASURED_PEAK_LOW = 300, MEASURED_PEAK_HIGH = 350;
const float ADC_NOISE_SIGMA = 20.0f;      // pessimistic default until NoiseLog is run (motors ON)
const float DETECT_RANGE_MAX_CM = 80.0f;
const float SENSOR_REFRESH_NOMINAL_MS = 38.3f; // GP2Y0A21 datasheet
const float SENSOR_REFRESH_JITTER_MS = 9.6f;
const int STRONG_CONFIRM_SAMPLES = 2;
const float LOST_CONTACT_GRACE_FLOOR_MS = 60.0f;
const bool PHANTOM_GATE_ENABLED = false;
const bool EDGE_SUPPRESSION_ENABLED = false;
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

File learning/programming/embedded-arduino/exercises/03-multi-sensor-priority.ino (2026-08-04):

/*
  Exercise 03 - Multi-Sensor Priority Logic
  Goal: Understand else-if chains with multiple inputs, and WHY order matters.

  This is a stand-in for the real sumo robot's decision logic:
  - Button on pin 2  = stand-in for "opponent detected" sensor
  - Button on pin 3   = stand-in for "edge detected" sensor

  Hardware: Arduino Uno + 2 pushbuttons (same wiring pattern as Exercise 02 -
  one leg from EACH contact, not both legs of the same contact)

  Why edge-check is checked FIRST:
  if/else-if chains are checked top to bottom, and the FIRST true condition
  wins - the rest are skipped, even if they'd also be true. If "opponent
  detected" were checked before "edge detected", the robot could attack its
  way straight over the edge whenever both were true at once. Putting the
  safety check (edge) first guarantees it always overrides everything else,
  every single loop cycle, no matter what else is happening.

  This structure is IDENTICAL to the real Besomi kit's loop() - just with
  buttons standing in for the actual IR/line sensors.
*/

void setup() {
  pinMode(13, OUTPUT);
  pinMode(2, INPUT_PULLUP);  // pretend: opponent detected sensor
  pinMode(3, INPUT_PULLUP);  // pretend: edge detected sensor
  Serial.begin(9600);
}

void loop() {
  int opponentDetected = digitalRead(2);
  int edgeDetected = digitalRead(3);

  if (edgeDetected == LOW) {
    // Safety check - always checked FIRST, always wins
    Serial.println("ACTION: EDGE ESCAPE");
    digitalWrite(13, LOW);
  }
  else if (opponentDetected == LOW) {
    Serial.println("ACTION: ATTACK");
    digitalWrite(13, HIGH);
  }
  else {
    Serial.println("ACTION: SEARCH");
    digitalWrite(13, LOW);
  }
}

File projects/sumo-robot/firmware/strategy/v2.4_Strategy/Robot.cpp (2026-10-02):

#include <Arduino.h>
#include <math.h>
#include "Hardware.h"
#include "Motors.h"
#include "Sensors.h"
#include "Map.h"
#include "Strategy.h"
#include "Robot.h"

enum EdgeRecoveryPhase
{
    EDGE_RECOVERY_IDLE,
    EDGE_RECOVERY_ACTIVE
};
static EdgeRecoveryPhase edgePhase = EDGE_RECOVERY_IDLE;
static bool edgeFrontTriggered = false;
static unsigned long edgeRecoverStartMs = 0;
static unsigned long edgeClearedAtMs = 0;
static unsigned long lastTickMs = 0;

static bool doubleEdgeActive = false;
static unsigned long doubleEdgeStartMs = 0;
static bool doubleEdgeDriveForward = true;

static float normalizeDeg180Local(float deg)
{
    while (deg > 180.0f)
        deg -= 360.0f;
    while (deg < -180.0f)
        deg += 360.0f;
    return deg;
}

static void computeEdgeEscapeDrive(int &leftPwm, int &rightPwm)
{
    int speed = anyContact(getOpponentDetection()) ? DRIVE_PWM_MAX : EDGE_RECOVER_SPEED; // in contact: full effort, 170 loses the push
    int baseSpeed = edgeFrontTriggered ? -speed : speed;
    int trim = 0;

    if (!isMapVoid())
    { // rarely true right after a snap — U resets to ~U0 on every snap
        float travelHeadingDeg = normalizeDeg180Local(getPose().thetaDeg + (edgeFrontTriggered ? 180.0f : 0.0f));
        float turnDeltaDeg = normalizeDeg180Local(getReturnHeadingDeg() - travelHeadingDeg);
        trim = (int)(EDGE_ESCAPE_TRIM_MAX * sinf(turnDeltaDeg * DEG_TO_RAD)); // sign unverified — bench check, see ALIGN_LEFT precedent
    }

    leftPwm = baseSpeed - trim;
    rightPwm = baseSpeed + trim;
}

static void handleEdgeRecoveryTick(const EdgeReadings &e, unsigned long dtMs)
{
    unsigned long now = millis();
    OpponentDetection d = getOpponentDetection();

    bool oppositeTriggered = edgeFrontTriggered ? e.back : e.front;
    bool stillOnEdge = edgeFrontTriggered ? e.front : e.back;
    bool clearedLongEnough = false;
    bool swingClear = getRadiusFromCenter() + ROBOT_R_SWING_CM <= ARENA_OUT_RADIUS_CM;

    if (stillOnEdge)
    {
        edgeClearedAtMs = 0;
    }
    else if (edgeClearedAtMs == 0)
    {
        edgeClearedAtMs = now;
    }
    else if (now - edgeClearedAtMs > EDGE_CLEAR_CONFIRM_MS + EDGE_OVERRUN_MS && swingClear)
    {
        clearedLongEnough = true;
    }

    bool timedOut = (now - edgeRecoverStartMs) > EDGE_RECOVER_MAX_MS;

    if (oppositeTriggered || clearedLongEnough || timedOut)
    {
        stopMotors();
        edgePhase = EDGE_RECOVERY_IDLE;
        if (anyOpponentDetected(d) && !oppositeTriggered && swingClear)
            strategyEngage(); // left/right -> ALIGN, center -> COMMIT
        else
            strategyForceReturn();
        return;
    }

    int leftPwm, rightPwm;
    computeEdgeEscapeDrive(leftPwm, rightPwm);
    drive(leftPwm, rightPwm, true);
    mapUpdateMotion(leftPwm, rightPwm, dtMs);
}

static bool buttonDown(int pin)
{
    if (START_SWITCH_ANALOG && pin == START_BUTTON_PIN)
    {
        (void)analogRead(pin); // dummy read: the ADC still holds the previous channel
        return analogRead(pin) > START_SWITCH_THRESHOLD_ADC;
    }
    return (digitalRead(pin) == HIGH) != BUTTON_ACTIVE_LOW;
}

// Blocks until `pin` has been RELEASED for a stable window and then PRESSED for a stable window.
// Requiring release first means a held/stuck/shorted button can never trigger anything, and a
// button still held from the previous step must be let go and pressed again.
// Motors are forced to 0 the whole time; sensors are polled if they are already powered.
static void waitForPress(int pin, bool pollSensors)
{
    unsigned long t = millis();
    while (millis() - t < BUTTON_DEBOUNCE_MS)
    {
        stopMotors();
        if (pollSensors)
            updateOpponentSensors();
        if (buttonDown(pin))
            t = millis();
        delay(1);
    }
    t = millis();
    while (millis() - t < BUTTON_DEBOUNCE_MS)
    {
        stopMotors();
        if (pollSensors)
            updateOpponentSensors();
        if (!buttonDown(pin))
            t = millis();
        delay(1);
    }
}

static bool constantsValid()
{
    return DRIVE_SPEED_MAX_CMS > 0 && SPIN_RATE_CW_DEGS > 0 && SPIN_RATE_CCW_DEGS > 0 &&
           STOP_DISTANCE_CM > 0 && FRICTION_MU > 0 && DETECT_RANGE_MAX_CM > 0 &&
           isfinite(DRIVE_DECEL_CMS2) && isfinite(COMMIT_SOFT_START_S) && isfinite(SEARCH_SPIN_CAP_DEGS) &&
           isfinite(ALIGN_ACTUAL_SPIN_DEGS) && ALIGN_ACTUAL_SPIN_DEGS > 0 &&
           SEARCH_SPIN_PWM > 0 && OPEN_SWEEP_LEG_A_MS > 0 && ALIGN_TIMEOUT_MS > 0 &&
           ADC_OVERSAMPLE_N >= 1 && ADC_OVERSAMPLE_N <= ADC_OVERSAMPLE_MAX &&
           COMMIT_SOFT_START_S > 0 && isfinite(MOTOR_SLEW_PWM_PER_MS) && MOTOR_SLEW_PWM_PER_MS > 0 &&
           isfinite(SEARCH_ACTUAL_SPIN_DEGS) && SEARCH_ACTUAL_SPIN_DEGS > 0 &&
           WEAK_THRESHOLD < STRONG_THRESHOLD && STRONG_THRESHOLD < NEAR_THRESHOLD;
}

static bool startReleasedSinceStart = false;
static unsigned long stopSince = 0;

// STAGES 2-4: idle until BUTTON 2, mandatory 5 s stationary delay, then hand over to the strategy.
static void armAndStart()
{
    stopMotors();
    initMap();
    primeOpponentSensors();
    waitForPress(START_BUTTON_PIN, true); // STAGE 2
    calibrateEdgePolarity();              // robot is on the black surface right now: learn which pin state means white

    unsigned long holdStart = millis(); // STAGE 3
    while (millis() - holdStart < START_COUNTDOWN_MS)
    {
        stopMotors();
        updateOpponentSensors();
    }

    resetStrategy(anyOpponentDetected(getOpponentDetection())); // STAGE 4
    edgePhase = EDGE_RECOVERY_IDLE;
    doubleEdgeActive = false;
    lastTickMs = millis();

    startReleasedSinceStart = false;
    stopSince = 0;
}

void initRobot()
{
    // STAGE 0 - boot: everything off. Drivers disabled, no sensor reads, no logic.
    disableMotorDrivers();
    if (!constantsValid())
        while (true)
            delay(1000); // bad/zero/NaN constant: stay dead at the bench instead of driving on garbage
    pinMode(START_BUTTON_PIN, BUTTON_ACTIVE_LOW ? INPUT_PULLUP : INPUT);

    // STAGE 1 - BUTTON 1 (A3): power up. Drivers enabled (PWM 0), sensors live. NO logic, no timers.
    if (POWER_BUTTON_PRESENT)
    {
        pinMode(POWER_BUTTON_PIN, BUTTON_ACTIVE_LOW ? INPUT_PULLUP : INPUT);
        waitForPress(POWER_BUTTON_PIN, false);
    }
    initMotors();
    initSensors();
    armAndStart();
}

static void handleDoubleEdgeTick(const EdgeReadings &e, unsigned long dtMs)
{
    if (!e.front || !e.back)
    {
        stopMotors();
        doubleEdgeActive = false;
        return;
    }
    if (millis() - doubleEdgeStartMs > DOUBLE_EDGE_RECOVER_MAX_MS)
    {
        stopMotors();
        doubleEdgeActive = false;
        return;
    }

    int speed = doubleEdgeDriveForward ? EDGE_RECOVER_SPEED : -EDGE_RECOVER_SPEED;
    drive(speed, speed, true);
    mapUpdateMotion(speed, speed, dtMs);
}
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

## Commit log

2026-07-24 Testing adding a single file to staged area and then pushing it onto repo
2026-07-31 refactor: simplify folder structure and reorganize learning materials
2026-08-04 Test .ino files for arduino c programming
2026-08-04 Add notes of C arduino
2026-08-04 Add blink led code
2026-08-04 Write button led
2026-08-04 Code Multi-Sensor Logic
2026-08-04 Update button to toggle
2026-09-15 test: button_led.ino wokwi code
2026-09-15 test: button_toggle_edge_Sensor.ino wokwi code logic
2026-09-15 arduino fundamentals
2026-09-15 Wiring guide for assembling and coding
2026-09-17 Add Sumo Robot motor control module
2026-09-17 Add Sumo Robot sensor module
2026-09-18 Add round switch pin and motor polarity configuration
2026-09-18 Refactor motor control through drive function
2026-09-18 Add sensor debug output interface
2026-09-18 Add sensor debug output implementation
2026-09-18 Remove obsolete Arduino learning files
2026-09-19 add sumo robot final design along with detachable parts
    [Final_Sumo_Robot.stl, Robot_cylinder.stl, robot_detachable_roof.stl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]
2026-09-20 update: motors logic
2026-09-20 update: sensors logic
2026-09-23 test: design ai refactored
    [front_wedge.stl, main_deck.stl]
2026-10-01 Reorganize Sumo Robot project structure
    [Final_Sumo_Robot.stl, Robot_cylinder.stl, front_wedge.stl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]
2026-10-01 Add Strategy 5 motor implementation
2026-10-01 Add Strategy 5 motor definitions
2026-10-01 Add Strategy 5 sensor implementation
2026-10-01 Add Strategy 5 sensor definitions
2026-10-01 Add GP2Y0A21 sensor tests
2026-10-01 Add motor and sensor bench tests
2026-10-01 Add robot sensor test
2026-10-01 Add robot motor test
2026-10-01 Add TCRT5000 sensor tests
2026-10-02 update: map uses actual motor data
2026-10-02 fix: edge cases and errors
    [Robot.cpp]
2026-10-02 add noise log file - to be used during testing
    [NoiseLog.ino]
2026-10-02 update: replaced old constants with the new constants to use motor data for map
    [Robot.cpp]
2026-10-02 fix: bug fixes and updates on the switch
    [Hardware.h, Map.cpp, Robot.cpp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]
2026-10-04 upload design test files
    [front_wedge.stl, main_deck.stl]
2026-10-04 upload design - except final
    [Final_Sumo_Robot.stl, Robot_cylinder.stl, Sumo body v4.step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]
2026-10-07 Move notes and exercises into learning/, fix 'excercises' typo, group Arduino notes and exercises
    [01-blink-led.ino, 02-button-led.ino, 03-multi-sensor-priority.ino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]
2026-10-07 Move roadmap to lowercase with kebab-case file names
2026-10-07 Sumo-Robot: move CAD models and parametric scripts under design/
    [Final_Sumo_Robot.stl, Robot_cylinder.stl, Sumo body v4.step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]
2026-10-07 Rename Monte Carlo folders to current/ and archive/, move projects to lowercase, update projects index
2026-10-07 Add dated journal ledger and playground README
2026-10-11 remove obsolete old file tracements
2026-10-15 amd-hackathon-act-iii: fix package init files (stage exports belong in src/stages/__init__.py)
2026-10-15 amd-hackathon-act-iii: STATE and LOG updated after backend code stages
2026-10-16 feat: improve evaluation pipeline and analytics dashboard
    - Refine pipeline stages for loading, matching, and judging
    - Update benchmark evaluation and runtime configuration
    - Add and update backend pipeline and stage tests
    - Improve frontend data loading, analytics, review, and upload views
    - Update fake data generation and backend data synchronization
    - Add frontend analytics and data loader tests
    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
2026-10-17 chore: apply kebab-case naming, move workflow docs to projects/, index EA certificate
